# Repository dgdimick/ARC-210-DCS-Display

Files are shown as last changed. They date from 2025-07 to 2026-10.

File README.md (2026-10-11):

# ARC-210 Radio Control Panel for DCS A-10C II using a 3.5" TFT SPI display and DCSBIOS

This project is an ARC-210 radio control panel for the DCS A-10C II using a Teensy 4.1, an ILI9488 TFT display,
and DCS-BIOS for live radio data and cockpit control.

<p align="center">
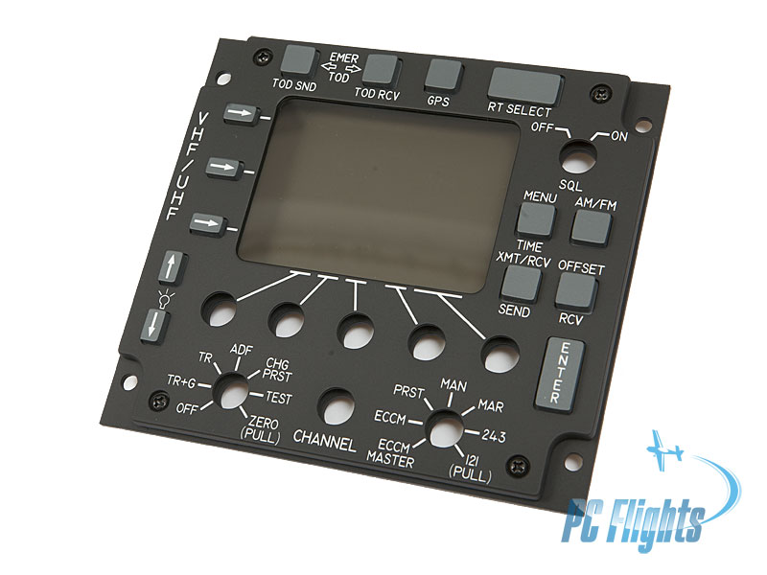
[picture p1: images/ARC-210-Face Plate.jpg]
ARC-210 Face Plate
  
</p>

**October 10, 2026 — Splash-screen picture removed**

I removed `splash_screen.jpg` because [ARC-210-Face Plate.jpg](images/ARC-210-Face%20Plate.jpg) is a better picture. The faceplate picture remains at the top of this README.

**October 10, 2026 — Outdated Button PCB image removed**

I removed `Button_Ver2.0.jpg` because it does not show the final Button PCB. I am redesigning the 16-button board and removed the old picture to prevent confusion.

**October 10, 2026 — Rotary Encoder PCB project published**

I have published the [Rotary Encoder KiCad project](PCBs/Rotary%20Encoders/), including the schematic, PCB, custom libraries and header wiring instructions. The schematic and PCB pass their configured checks. I have confirmed that the printed rotary-encoder STL fits and all six encoders work in the final combined hardware test.

**October 10, 2026 — Final hardware test HEX**

The [final hardware test HEX](Firmware/Test%20Code/ARC210_Final_Hardware_Test_Teensy41.hex) is now available for Teensy 4.1. This combined TFT test checks all 16 buttons, six rotary encoders, brightness controls, and both seven-position rotary switches on GPIO 14 and 15. All of these functions were confirmed working together on the panel. See the [test instructions](Firmware/Test%20Code/ARC210_Button_Test/README.md).

**October 10, 2026 — Two PCBs remaining**

With the combined hardware test confirmed working, the remaining PCB work is the **Main Controller board** and a **redesign of the 16-button board** to improve button alignment with the faceplate.

**Updated October 10, 2026 — Rotary Switch PCB version 1.2 adds On/Off support**

Two new 3D PCB pictures have been uploaded to the `images` directory: the [Rotary Switch PCB](images/Rotary-Switch-PCB-3D.png) and [Rotary Encoder PCB](images/Rotary-Encoder-PCB-3D.png). The new PCBs are still in development. The corrected [Rotary Switch PCB project, version 1.2](PCBs/Rotary%20Switches/), is now available with its schematic, PCB and custom libraries. Terminal 1 is used for the first position, and the PCB matches the corrected schematic. Version 1.2 replaces the withdrawn initial version; use the new files. I modified the PCB so it can also be used with the On/Off switch. For On/Off use, omit R1–R6 and solder across **JP1**, marked **ON/OFF** on the back of the PCB. JP1 connects the R1–R2 junction (R2 pad 1 / switch terminal 2) to GND; connect J1 pin 2 to a Teensy input with a pull-up. For the normal resistor ladder, install R1–R6 and leave JP1 open. The PCB pictures remain available as development previews.

Panel/button illumination LEDs have been dropped due to insufficient clearance with the TFT display. The [parts list](parts/BOM.csv) now excludes the panel LEDs and their current-limiting resistors. The TFT display and its backlight remain. Existing schematic drawings may still show the former panel-lighting circuit.

**September 29, 2026 — Rotary encoder test HEX available**

The current HEX is available for testing the ARC-210 menu screens and navigation, including the HQ, COMSEC, and RADIO SETTINGS menus. This is a menu-system preview, not a finished radio implementation: some menu actions and synchronization still need work.

The current `Master_Program.ino.hex` works with DCS-BIOS while running DCS, but it is **display-only at this time**. It displays radio information from the game; physical panel controls do not yet operate the in-game radio.

The HQ MORE loop and detail screens are implemented. LOAD WOD has been tested against DCS: the displayed number matches, follows MLSK changes, and resets to 20 on re-entry in the tested session. MENU exits from the opening screen listing HQ MENUS / COMSEC / RADIO SETTINGS and is inactive on deeper pages.

Download [Master_Program.ino.hex](Firmware/Master%20Hex%20Files/Master_Program.ino.hex). Read the [preview notes and required DCS-BIOS export changes](Firmware/Master%20Hex%20Files/README.md) before testing. The display starts blank until it receives powered-radio data from DCS-BIOS.

### Rotary encoder test HEX download

Download [ARC210_Encoder_Check_Teensy41.hex](Firmware/Test%20Code/ARC210_Encoder_Check_Teensy41.hex) for standalone testing of all six rotary encoders on a Teensy 4.1. The TFT displays each encoder's raw count, direction, and A/B input states. DCS is not required, and the backlight stays fully on using Teensy pin 4.

**First pass the TFT hello test before loading the encoder test.** A working TFT is required to see the results. See the [test instructions](Firmware/Test%20Code/README.md) and [pin layout](Docs/ARC-210%20Teensy%204.1%20Pin%20layout.txt). Loading this HEX replaces the firmware currently on the Teensy.

Here is a short video showing the progress I have made so far:

[ARC-210 Project Progress Video](https://drive.google.com/file/d/162CAG3RlfPK6QnCSb0p5lkmVlXDZjPrU/view)

I am looking for **beta testers** to help with screen layouts, placement of the lines, and font suggestions. If you have a **3.5-inch SPI TFT display** and a **Teensy 4.1** lying around, you have the basic hardware needed to beta test.

The `Teensy_TFT_Hello_Works.ino` file in the `Firmware` directory contains the correct display pin assignments and can be used to verify that your display is connected correctly.

The HEX file for the current state of the project is located in:

`Firmware/Master Hex Files/`

If you own a Teensy 4.1, you may already know how to install a HEX file. If not, here are the steps.

## Loading the HEX File onto a Teensy 4.1

1. Install and open **Teensy Loader, you can find it in the firmware directory**.
2. Open the supplied `Master_Program.ino.hex` file.
3. Connect the Teensy 4.1 to your computer by USB.
4. Press the button on the Teensy if it does not enter programming mode automatically.
5. Click **Program** in Teensy Loader.
6. Reboot the Teensy.

> **Note:** This repository is now included in the A-10-Sim repository.

This project replicates the look and functionality of the **ARC-210 VHF/UHF radio** used in the A-10C II Warthog module for Digital Combat Simulator (DCS).

It is intended for use with a physical control panel powered by a Teensy 4.1.

[See the official DCS website](https://www.digitalcombatsimulator.com/en/)

## Features

- Interface modeled after the ARC-210 radio
- Powered by one Teensy 4.1
- ILI9488 3.5-inch SPI TFT display (480 × 320)
- Support for digital rotary encoders, rotary switches, and momentary switches
- **Planned button support:** All panel buttons will be wired, and their in-game functions will be supported wherever DCS-BIOS provides the necessary controls. The current HEX remains display-only.
- DCS-BIOS integration for in-game control and feedback
- ARC-210 startup and initialization screens
- Live frequency display from DCS-BIOS
- AM/FM modulation display
- UNAVAILABLE screen for the appropriate Frequency and Mode switch selections

## Tools Needed

- Soldering iron
- 3D printer, or access to one
- Flush wire cutters
- USB Micro-B cable for programming the Teensy 4.1 and connecting the unit to the computer

## Why I had to use a Teensy

The ARC-210 panel needs a lot of GPIO (general-purpose input/output) pins. It is not just driving a display: the same controller also has to read the knobs and switches, scan the buttons, and control the TFT backlight.

- Each rotary encoder needs two input pins to detect movement and direction.
- The 16 push buttons use a 4 × 4 matrix, which still needs eight GPIO pins for its rows and columns.
- The rotary-switch resistor ladders need analog inputs, and the squelch switch needs another input.
- The SPI TFT needs clock and data connections plus control signals for chip select, reset, and data/command selection.
- The TFT display backlight needs a control output.

These connections add up quickly. I chose the Teensy 4.1 because it gives this design enough pins to connect the controls and display directly, without adding GPIO expanders or another controller. Using one controller for all six PCBs also keeps the wiring and firmware easier to manage.

### Could I have used several Arduinos?

Yes. I could have split the buttons and switches onto one Arduino, the rotary encoders onto another, and the TFT onto a controller with enough processing speed and memory for the display. Depending on the DCS-BIOS connection setup, the boards could use separate USB connections or communicate through a main controller.

That would provide more GPIO, but it would also mean more wiring, connections, and separate firmware to maintain. Splitting the controls across boards would not increase the memory or processing speed of the board driving the TFT. An Uno or Mega would still have its own display limitations.

I chose the Teensy 4.1 because it combines the GPIO, processing speed, and memory needed for this design on one board. Several Arduinos were an option; one Teensy keeps this build simpler.

The standard processor clock speeds are:

| Board | CPU clock speed |
| --- | ---: |
| [Teensy 4.1](https://www.pjrc.com/store/teensy41.html) | **600 MHz** |
| [Arduino Uno R3](https://docs.arduino.cc/hardware/uno-rev3/) | **16 MHz** |
| [Arduino Mega 2560 Rev3](https://docs.arduino.cc/hardware/mega-2560/) | **16 MHz** |

The Teensy 4.1 has **37.5 times the CPU clock frequency** of these classic Arduino boards. That is a clock-speed comparison, not a measured 37.5-times improvement in screen refresh rate; processor architecture, memory, SPI speed, and the display code also affect the result.

Display response speed was another major factor in my choice. Compared with classic Arduino Uno and Mega boards, the Teensy 4.1 provides much more processing headroom for drawing the TFT while handling radio updates and controls. I would not expect those older boards to deliver the same screen response with this display and firmware. Actual refresh speed also depends on the SPI connection, display library, and drawing code; this comparison is not a claim about every Arduino model.

### The same Arduino programming workflow

The Teensy is programmed using the same **Arduino IDE** and **`.ino` sketches** used for Arduino boards. The familiar editor, C++ sketch structure, and `setup()` / `loop()` workflow remain the same, so there is no need to learn a different programming environment for this project.

Install [Teensy board support](https://www.pjrc.com/teensy/td_download.html) and select Teensy 4.1 in the IDE. [Teensy Loader](https://www.pjrc.com/teensy/loader.html) handles uploading the compiled firmware and is integrated with the Arduino upload workflow. To use the precompiled `Master_Program.ino.hex` supplied here, simply open it in Teensy Loader and program the board; you do not need to compile the sketch yourself.

The programming workflow is familiar, although pin assignments and hardware-specific libraries still need to match the Teensy rather than an Uno or Mega.

### Cost: one Teensy versus three Arduinos

For a board-only comparison, these US-dollar prices were checked on September 24, 2026:

| Option | Price per board | Quantity | Total |
| --- | ---: | ---: | ---: |
| [Teensy 4.1 without Ethernet — SparkFun](https://www.sparkfun.com/teensy-4-1-without-ethernet.html) | $29.60 | 1 | **$29.60** |
| [Official Arduino Uno R3 — Arduino US store](https://store-usa.arduino.cc/products/arduino-uno-rev3) | $27.60 | 3 | **$82.80** |

At those listed prices, one Teensy costs **$53.20 less** than three official Uno R3 boards, before tax, shipping, cables, headers, or other accessories. Lower-cost Arduino-compatible boards can change the comparison substantially. This is an illustrative cost comparison, not a claim that three Unos would run the current display firmware or provide equivalent screen performance. Prices may change.

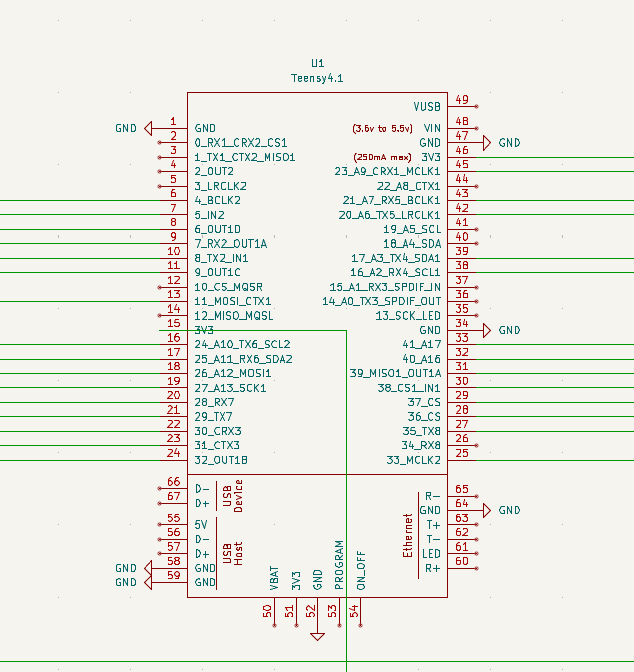
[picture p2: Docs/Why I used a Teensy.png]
Teensy 4.1 schematic showing the panel connections


The numbers around this schematic symbol are KiCad pad numbers; use the signal labels and the project wiring documentation to identify the corresponding Teensy GPIO pins.

## Six-PCB layout

The radio will use a total of **six PCBs**, controlled by one Teensy 4.1:

- **Master PCB:** carries the Teensy, power circuitry, display and control connections.
- **Button PCB:** carries the push-button switches behind the faceplate and connects to the master PCB.
- **Rotary Encoder PCB:** carries the rotary encoders and connects to the master PCB.
- **Three small Rotary Switch PCBs:** the two seven-position switches and the On/Off switch will each have their own PCB for cleaner wiring and better wire support.

All three Rotary Switch PCBs use the same design and are interchangeable. For the **On/Off rotary switch PCB**, install **no resistors** (omit R1–R6) and bridge the small **JP1 solder pad**, marked **ON/OFF**, with solder. For either seven-position rotary switch PCB, install the six resistors and leave JP1 open.

The button, rotary encoder, and rotary switch PCBs do not require additional microcontrollers. The two remaining PCB tasks are the Main Controller board and the redesign of the 16-button board.

## Parts

See the [parts directory](parts/) for the [component list (BOM)](parts/BOM.csv), hardware supplier links, and switch-fit and compatibility notes.

## Software

- Written in Arduino C++
- Uses DCS-BIOS for communication with DCS
- Firmware and test files are maintained in this repository

## ARC-210 Bench Testing App

The [working ARC-210 version of dcsBiosDebug](https://github.com/dgdimick/dcsBiosDebug/tree/arc210-working) is maintained in a separate repository. It provides buttons for menu testing and separate Frequency, Secondary, and Master controls for sending simulated DCS-BIOS data to your Teensy without running DCS.

Download the **arc210-working** branch using **Code → Download ZIP**, extract it, and keep its `icons` folder beside the Python script. With Python 3 and Tkinter installed, open a terminal in that folder and run:

```cmd
python -m pip install numpy pyserial Pillow
python dcsBiosDebug.py
```

Use the Python script, including the `.py` extension; the original bundled executable does not include the ARC-210 controls. Select your Teensy's serial port and click **Connect**. Choose **2 - TR** and click **Set Master** for the normal radio switch position, or **0 - OFF** to test power off.

See the [full testing instructions and compatibility notes](https://github.com/dgdimick/dcsBiosDebug/blob/arc210-working/ARC210_TESTING.md). The shortcuts use fixed A-10C II addresses and send data to the hardware, not commands to DCS. Some firmware states require additional exports through the normal instrument controls.

## Directories

- `ARC-210/` — project root
- `ARC-210/Firmware/` — firmware and test files\n- `ARC-210/Firmware/Boot Loader/` — precompiled Teensy HEX files for loading with Teensy Loader or TyTools
- [`parts/`](parts/) — component list, hardware supplier links, and compatibility notes
- `ARC-210/Docs/` — schematics, diagrams, and documentation
- `ARC-210/images/` — project images
- `ARC-210/Supporting STL's/` — 3D-printable knobs, bezels, brackets, mounts, and other parts

## Supporting STL Files

The `Supporting STL's` directory includes:

- Knobs for rotary encoders and rotary switches
- Mounting hardware for the TFT screen and PCBs
- Brackets for panel alignment

All STL files are intended to be print-ready for FDM printers using a 0.4 mm nozzle. Resin/SLA printers may require different settings or scaling.

## PC Flights affiliation

I am not affiliated with [PC Flights](https://pcflights.com/) in any way. I simply chose to use their panels for my own cockpit projects.

## Licensing

- **PCBs:** CERN Open Hardware Licence Version 2 - Permissive (CERN-OHL-P-2.0)
- **Teensy firmware:** MIT License
- **STL files:** Creative Commons Attribution 4.0 International (CC BY 4.0)

See the `Docs` directory for copies of the applicable licenses.

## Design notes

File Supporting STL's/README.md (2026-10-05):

# ARC-210 Supporting 3D Files

## Knob Set V3

Updated October 4, 2026.

**Knob Set V3** identifies this collection. Each knob retains its own revision number; the collection number does not reset or replace those numbers.

### Current published knobs

| Knob | Current STL | Earlier file |
| --- | --- | --- |
| Frequency | [Freq_Knob_v10.stl](Freq_Knob_v10.stl) | Replaces `Freq Mesh v9.stl` |
| Mode | [Mode_Knob_v4.stl](Mode_Knob_v4.stl) | Supersedes `Mode Mesh v6.stl`, despite its higher filename number |
| Channel | [Channel_Knob_v3.stl](Channel_Knob_v3.stl) | Replaces `Channel Knob v13.stl`, despite its higher filename number |

### If you downloaded an older ZIP

Download the current files linked above. Do not mix the older frequency, mode, or channel STLs with Knob Set V3. The old filenames have been removed from the current branch, but may still exist in previously downloaded ZIPs or repository history.

`Channel_Knob_v3.stl` is the current channel knob for Knob Set V3. Its lower filename number does not mean it is older than `Channel Knob v13.stl`. Use the linked files above to identify the current versions.

### Printing and fit

Use the hardware listed on the main project page. Earlier printing notes reported needing 106% scale for the mode and frequency knobs on the author's printer. That is a historical fit adjustment, not a verified requirement for every current STL or printer. Check shaft fit before printing the full set; scaling changes both the outside dimensions and the holes.

## Display bracket

The 3.5 SPI display mount does not have mounting points. It is a bracket that holds the display between the PCB and front face and currently needs to be hot-glued in place. A proper mounting arrangement is planned.

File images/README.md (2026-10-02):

# Project images and media

[Additional project media (Google Drive)](https://drive.google.com/file/d/1D4GuG0yuVBumasEVbqX7CI54fbOVu1nT/view?usp=sharing)

## Buttons and encoder test

[View the buttons and encoder test, including the menus working with the buttons](https://drive.google.com/file/d/162CAG3RlfPK6QnCSb0p5lkmVlXDZjPrU/view).

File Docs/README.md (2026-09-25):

# ARC-210 Documentation

## Why I used a Teensy

[Why I used a Teensy.png](Why%20I%20used%20a%20Teensy.png) is a screenshot of the Teensy 4.1 symbol and its connections in the ARC-210 panel's KiCad schematic. The green lines are electrical connections to the rest of the circuit. It shows how many connections are needed to bring the display, controls, and lighting together on one controller.

Teensy 4.1 connections in the ARC-210 schematic

### Why the GPIO count matters

GPIO means general-purpose input/output. These are the pins the controller uses to read controls and send signals to other hardware. This panel needs pins for several jobs:

- Rotary encoders each use two input signals to detect movement and direction.
- The 16 buttons use a 4 × 4 matrix, requiring eight pins for the rows and columns instead of a separate pin for every button.
- The SPI TFT needs clock and data signals, plus chip-select, data/command, and reset connections.
- The display backlight and panel lighting have separate control signals.
- Other switches need inputs, and the current pin layout reserves two pins for I²C.

Even with a button matrix, the connections add up quickly. The Teensy 4.1 provides enough pins for this design without adding GPIO expanders or a second controller. That keeps the wiring and firmware easier to manage.

### Could I have used several Arduinos?

Yes. I could have split the buttons and switches onto one Arduino, the rotary encoders onto another, and the TFT onto a controller with enough processing speed and memory for the display. Depending on the DCS-BIOS connection setup, the boards could use separate USB connections or communicate through a main controller.

That would provide more GPIO, but it would also mean more wiring, connections, and separate firmware to maintain. Splitting the controls across boards would not increase the memory or processing speed of the board driving the TFT. An Uno or Mega would still have its own display limitations.

I chose the Teensy 4.1 because it combines the GPIO, processing speed, and memory needed for this design on one board. Several Arduinos were an option; one Teensy keeps this build simpler.

The standard processor clock speeds are:

| Board | CPU clock speed |
| --- | ---: |
| [Teensy 4.1](https://www.pjrc.com/store/teensy41.html) | **600 MHz** |
| [Arduino Uno R3](https://docs.arduino.cc/hardware/uno-rev3/) | **16 MHz** |
| [Arduino Mega 2560 Rev3](https://docs.arduino.cc/hardware/mega-2560/) | **16 MHz** |

The Teensy 4.1 has **37.5 times the CPU clock frequency** of these classic Arduino boards. That is a clock-speed comparison, not a measured 37.5-times improvement in screen refresh rate; processor architecture, memory, SPI speed, and the display code also affect the result.

Display response speed was another major factor in my choice. Compared with classic Arduino Uno and Mega boards, the Teensy 4.1 provides much more processing headroom for drawing the TFT while handling radio updates and controls. I would not expect those older boards to deliver the same screen response with this display and firmware. Actual refresh speed also depends on the SPI connection, display library, and drawing code; this comparison is not a claim about every Arduino model.

### The same Arduino programming workflow

The Teensy is programmed using the same **Arduino IDE** and **`.ino` sketches** used for Arduino boards. The familiar editor, C++ sketch structure, and `setup()` / `loop()` workflow remain the same, so there is no need to learn a different programming environment for this project.

Install [Teensy board support](https://www.pjrc.com/teensy/td_download.html) and select Teensy 4.1 in the IDE. [Teensy Loader](https://www.pjrc.com/teensy/loader.html) handles uploading the compiled firmware and is integrated with the Arduino upload workflow. To use the precompiled `Master_Program.ino.hex` supplied here, simply open it in Teensy Loader and program the board; you do not need to compile the sketch yourself.

The programming workflow is familiar, although pin assignments and hardware-specific libraries still need to match the Teensy rather than an Uno or Mega.

### Cost: one Teensy versus three Arduinos

For a board-only comparison, these US-dollar prices were checked on September 24, 2026:

| Option | Price per board | Quantity | Total |
| --- | ---: | ---: | ---: |
| [Teensy 4.1 without Ethernet — SparkFun](https://www.sparkfun.com/teensy-4-1-without-ethernet.html) | $29.60 | 1 | **$29.60** |
| [Official Arduino Uno R3 — Arduino US store](https://store-usa.arduino.cc/products/arduino-uno-rev3) | $27.60 | 3 | **$82.80** |

At those listed prices, one Teensy costs **$53.20 less** than three official Uno R3 boards, before tax, shipping, cables, headers, or other accessories. Lower-cost Arduino-compatible boards can change the comparison substantially. This is an illustrative cost comparison, not a claim that three Unos would run the current display firmware or provide equivalent screen performance. Prices may change.

### Reading the diagram

The red numbers beside the symbol are KiCad pad numbers, **not necessarily the Teensy GPIO numbers used in the code**. The signal names identify the corresponding functions. Power and ground connections are also shown; they are not extra GPIO pins.

This image is a schematic excerpt, not a complete wiring guide. Use the [ARC-210 Teensy 4.1 pin layout](ARC-210%20Teensy%204.1%20Pin%20layout.txt) for the documented actual GPIO assignments, and check them against the firmware and PCB revision you are building.

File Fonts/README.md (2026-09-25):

# Current ARC-210 display font

The current menu-preview firmware uses `SwanseaFontSimple.cpp` and `SwanseaFontSimple.h`, copied from the working ARC210_Display library. These replace the older FreeSans headers previously stored here.

The renderer uses the Swansea28 bitmap glyph table with fractional scaling:

| Display element | Scale |
| --- | --- |
| Menu labels, EXIT, MORE, RT1 and PREV | 1.25× |
| Large frequency and channel/segment numbers | 3× |
| CT / CT-TD key number | 2× |
| Extra-long menu labels | 1× when needed to fit |

These are rendering scales, not point sizes. The files depend on Arduino and ILI9488_t3 and use the display library's global `tft` object; they are not standalone desktop font files or Adafruit GFX font headers.

Users installing the precompiled HEX do not need to install the fonts separately: the font data is already included in the firmware.

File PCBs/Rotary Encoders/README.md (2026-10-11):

# ARC-210 Rotary Encoder PCB

Published October 10, 2026. KiCad 10 project.

I have checked this six-encoder PCB against its schematic. The electrical check reported zero errors and warnings; the PCB check reported zero violations, zero unconnected pads and zero schematic parity issues under the project's saved check settings. Courtyard and certain footprint checks are disabled in those settings.

I printed the rotary-encoder STL and confirmed that it fits. I have also confirmed all six encoders working in the combined hardware test. A manufactured PCB still needs assembly and testing.

## Open the project

Download this folder and keep its contents together. Open `Rotary Encoders.kicad_pro` in KiCad 10. The custom symbol and footprint libraries are included and use project-relative paths. Install KiCad's standard symbol and footprint libraries as well.

Supplier encoder 3D models are optional and are not bundled. Existing model references now use project-relative paths: place the corresponding `.stp` files beside the project if you have them. The PEC11R model is a visual substitute; use the PEC11H part dimensions for mechanical checks. Missing models do not prevent opening or manufacturing the board.

## Parts and connections

- Six Bourns PEC11H-4220F-S0024 rotary encoders.
- J1: 14-pin header; use the assigned footprint to choose the connector.
- Both J1 pins 13 and 14 connect to GND, as do encoder common contacts and metal mounting tabs.
- The encoders' push-switch contacts S1 and S2 are deliberately unused and marked no-connect.

| J1 pin | Connection |
| --- | --- |
| 1 | SW1 B |
| 2 | SW1 A |
| 3 | SW2 A |
| 4 | SW2 B |
| 5 | SW3 B |
| 6 | SW3 A |
| 7 | SW4 A |
| 8 | SW4 B |
| 9 | SW5 B |
| 10 | SW5 A |
| 11 | SW6 B |
| 12 | SW6 A |
| 13 | GND (encoder commons and mounting tabs) |
| 14 | GND (encoder commons and mounting tabs) |

The tested physical Teensy GPIO pairs are: SW1 = 16/17, SW2 = 28/29, SW3 = 20/21, SW4 = 22/23, SW5 = 24/25 and SW6 = 26/27. Ensure all encoder commons share Teensy GND. The final [combined hardware test HEX](../../Firmware/Test%20Code/ARC210_Final_Hardware_Test_Teensy41.hex) provides counts and A/B diagnostics.

## Manufacturing files

This upload contains the editable project. Export copper, silkscreen, solder-mask and Edge.Cuts Gerbers plus drill files from KiCad for your PCB manufacturer. Review the manufacturer's preview before ordering.

PCB licensing: CERN-OHL-P-2.0, as specified in the repository.

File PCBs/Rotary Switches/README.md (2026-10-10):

# ARC-210 Rotary Switch PCB — Version 1.2

Updated October 10, 2026.

This corrected KiCad 10 project replaces the withdrawn initial version. Switch terminal 1 is used for position 1. The resistor ladder uses **six resistors (R1–R6)** to provide seven switch-position voltages. The switch contacts used are 1, 2, 4, 5, 7, 8 and 10; terminal 11 is unused. A1 is the common contact and analog output.

Open `Rotary Switches.kicad_pro`. The project includes its custom symbol and A12505RNCQ footprint, with relative library paths so they work after downloading.

- SW1: C&K A12505RNCQ, PCB terminals, 12.7 mm shaft, 45° indexing.
- R1–R6: **six resistors**, each 1 kΩ, 1%, 1/8 W.
- J1: pin 1 = 3.3 V; pin 2 = analog output; pin 3 = GND.

The 220 Ω resistor and 100 nF input filter belong near the Teensy on the master PCB.

## On/Off option added in version 1.2

I modified the PCB so it can also be used with the On/Off switch. **JP1**, marked **ON/OFF** on the back of the PCB near R2, is an open solder jumper between GND and the R1–R2 junction: R2 pad 1, also connected to switch terminal 2.

- **On/Off:** omit all six resistors R1–R6 and bridge JP1 with solder. Connect J1 pin 2 (switch common A1) to a Teensy input configured with a pull-up, and J1 pin 3 to GND. Selecting terminal 2 pulls the input LOW; an ungrounded contact reads HIGH. J1 pin 1 is not needed for this configuration. Set the switch travel and contact selection to match the panel markings.
- **Resistor ladder:** fit all six resistors R1–R6 and leave JP1 open. Use the three J1 connections listed above.

The solder-lug A12515RNZQ still requires mechanical support and wires to the corresponding PCB connections; it does not fit the PCB-pin footprint directly.

Validation: KiCad electrical checks reported zero violations; PCB checks reported zero violations, zero unconnected pads and zero schematic parity issues under the project's configured checks. Physical fit and operation have not yet been verified on a manufactured board.

The optional supplier 3D model is not bundled. To display it, place `A12503RNCQE.stp` beside the project files. That model represents the shorter shaft and is a visual reference; use the actual A12505RNCQ dimensions for mechanical clearance.

PCB design licensing: CERN-OHL-P-2.0, as specified in the repository.

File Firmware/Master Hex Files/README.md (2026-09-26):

# ARC-210 menu-system preview

README last updated: **September 25, 2026**.

`Master_Program.ino.hex` is the current Teensy 4.1 / ILI9488 480 × 320 display firmware, published for menu-screen and navigation testing. It is not a complete implementation of every radio function.

## What to test

- HQ MORE sequence: OPER. DATE LOAD -> VERIFY WOD/MWOD -> WOD LOAD -> WOD ERASE -> HQ II FMT -> OPER. DATE LOAD -> VERIFY WOD/MWOD, repeating from there.
- HQ detail screens, including WOD and HQII number positioning.
- MENU opens the opening menu from the frequency screen and closes it from that opening menu only. On all deeper pages it is inactive.
- LOAD WOD number synchronization with DCS, including MLSK increments. In the tested session both displays reset to 20 on re-entry; this is supplied by DCS, not hard-coded.
- LOAD HQII FMT exits to frequency when a frequency knob or Channel knob moves.
- Existing COMSEC and RADIO SETTINGS screen navigation.

## Known limitations

Some detail-page actions remain unimplemented, including the WOD erase YES outcome. COMSEC BASEBAND/DIPHASE selection synchronization needs further work because the game label depends on underlying settings. Early aircraft-power startup screens may lag DCS; frequency-screen timing and power behavior have been tested. Report the exact page, button/knob, and both DCS and physical-screen behavior when reporting an issue.

## Loading and first startup

Open this HEX in Teensy Loader, enable Auto, and press the Teensy's programming button. Reconnect your DCS-BIOS serial bridge after flashing if needed. The display starts blank until it receives powered-radio data; a blank screen without powered-radio updates from DCS-BIOS or dcsBiosDebug is expected. The Loader's “1% used” is memory usage, not upload progress.

## Test the menu system without running DCS

Use [dcsBiosDebug](https://github.com/dgdimick/dcsBiosDebug) to send simulated DCS-BIOS updates to the Teensy over USB serial. This lets you exercise the firmware's menu screens and navigation without launching DCS or loading a mission. See its [README and download links](https://github.com/dgdimick/dcsBiosDebug#downloads) for installation.

1. Load `Master_Program.ino.hex` onto the Teensy and connect the display hardware.
2. Close the DCS-BIOS serial bridge and any Serial Monitor using the Teensy's COM port.
3. In dcsBiosDebug, click **Find Serial Ports**, select the Teensy's COM port, and click **Connect**.
4. Load the matching A-10C aircraft JSON definition from your DCS-BIOS `doc/json` directory. Its output addresses and masks must match this firmware.
5. Add the ARC-210 power/master-switch and display-state outputs to **Active Indicators**. Send powered-radio values, including valid frequency/display data, and allow startup to finish. Connecting alone does not turn on the simulated radio; the screen can remain blank until the required data arrives.
6. Add the ARC-210 MENU, upper/middle/lower line-select key, and XMT/RCV button outputs. Simulate each press as **0 -> 1 -> 0**, allowing each state to be transmitted before changing it again. The firmware acts on the transition to 1, so release the button before testing another press.
7. Use these simulated updates to check the menu sequence, labels, layout, and navigation described above. Text outputs can be edited and sent with the **>** button; integer outputs can be changed with their sliders.

This is a bench test of the firmware's response to supplied data. dcsBiosDebug does not simulate DCS's radio logic or automatically provide the game's responses to hardware commands. Features such as WOD synchronization and game-dependent settings still need an in-DCS test. Disconnect dcsBiosDebug before reconnecting the normal DCS-BIOS serial bridge.

## DCS-BIOS export requirements

This build was tested with local changes to the A-10C DCS-BIOS export. Stock exports do not provide all the values used by these HQ screens. Back up your installed `Saved Games/DCS/Scripts/DCS-BIOS/lib/modules/aircraft_modules/A-10C.lua` before adapting the two existing getters below. Keep their existing lengths, ordering, and addresses; do not add duplicate definitions.

For `ARC210_VERIFY_WOD_ACTIVE_CHANNEL` (two characters, address `0x1338`), use:

```lua
return Functions.coerce_nil_to_string(arc_210_data["WOD_segment"] or arc_210_data["HQII_segment"] or arc_210_data["active_oper_date"] or arc_210_data["active_channel"])
```

For `ARC210_SELECTED_RT` (three characters, address `0x1320`), use:

```lua
return Functions.coerce_nil_to_string(arc_210_data["txt_RT"] or (arc_210_data["POWER UP LOADER"] and "PWR"))
```

Fully close and restart DCS after these changes. Reloading a mission or flashing the Teensy does not reload the Lua export. DCS-BIOS updates may overwrite these customizations. These getters only read the game's display data.

## File verification

Firmware build: **September 23, 2026**, originally published September 24, 2026. The September 25 README update adds offline testing instructions; the HEX file has not changed or been recompiled.

SHA-256:

```text
607418aa3843d871f3b5ff98abc2ede7575086a80b34e2273da59c333469278c
```

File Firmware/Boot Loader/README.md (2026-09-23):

# ARC-210 Teensy Firmware and Boot Loader Files

This directory contains the precompiled Teensy 4.1 firmware files for the ARC-210 DCS Display project. These files can be installed without compiling the Arduino source code.

The firmware files use the `.hex` extension.

## TyTools

You can find the complete TyTools instructions on the [official TyTools website](https://koromix.dev/tytools).

TyTools is a collection of independent programs for uploading firmware to, monitoring, and managing Teensy boards. Only one executable is needed for the function you want to use.

| Tool | Type | Description |
| --- | --- | --- |
| **TyCommander** | Qt graphical application | Upload, monitor, and communicate with multiple Teensy boards |
| **TyUploader** | Qt graphical application | Simple firmware and sketch uploader |
| **tycmd** | Command line | Command-line tool for managing Teensy boards |

Download the [latest TyTools release from GitHub](https://github.com/Koromix/tytools/releases). Development builds are available from [koromix.dev](https://koromix.dev/files/tytools/).

## Uploading with TyCommander or TyUploader

1. Download and install TyTools.
2. Connect the Teensy 4.1 to the computer with a USB cable.
3. Open **TyCommander** or **TyUploader**.
4. Select the Teensy 4.1.
5. Select the appropriate ARC-210 `.hex` file from this directory.
6. Start the upload.
7. If requested, press the physical programming button on the Teensy.

## Using `tycmd`

### List connected Teensy boards

```text
tycmd list
```

Use `--verbose` for additional device information:

```text
tycmd list --verbose
```

For structured output that can be processed by a script:

```text
tycmd list --output json
```

### Upload firmware

From this directory, upload a HEX file with:

```text
tycmd upload "<firmware-file>.hex"
```

If you run the command from the repository root, use:

```text
tycmd upload "Firmware/Boot Loader/<firmware-file>.hex"
```

Replace `<firmware-file>.hex` with the actual firmware filename.

By default, `tycmd` attempts to reboot the Teensy into its bootloader. Use `--wait` if you want it to wait for the bootloader to appear or for you to press the Teensy's programming button:

```text
tycmd upload --wait "Firmware/Boot Loader/<firmware-file>.hex"
```

## Selecting a Specific Teensy

When multiple Teensy boards are connected, select one with:

```text
tycmd <command> --board "[<serial>][-<family>][@<location>]"
```

The serial number, board family, and USB or operating-system location are optional filters. Run `tycmd list` to see the identifiers available on your computer.

| Board filter | Effect |
| --- | --- |
| `714230` | Select the board with serial number 714230 |
| `-Teensy` | Select a board in the Teensy family |
| `@usb-1-2-2` | Select the board connected at USB location `usb-1-2-2` |
| `@COM1` | Select the board associated with COM1 |
| `714230@usb-1-2-2` | Match both the serial number and USB location |

Examples:

```text
tycmd upload --board "714230" "Firmware/Boot Loader/<firmware-file>.hex"
tycmd upload --board "@COM5" "Firmware/Boot Loader/<firmware-file>.hex"
tycmd upload --board "@usb-1-2-2" "Firmware/Boot Loader/<firmware-file>.hex"
```

Using the USB-location form is useful in a simulator containing several Teensy boards because a device can remain associated with the same physical USB port.

## Serial Monitor

Open a serial connection with:

```text
tycmd monitor
```

Use `--reconnect` to reconnect automatically after a reset or brief USB disconnection:

```text
tycmd monitor --reconnect
```

Use `--raw` to send terminal input immediately without line buffering:

```text
tycmd monitor --raw
```

Teensy is a native USB device, so normal serial baud-rate settings are generally ignored by TyTools.

## Reset and Bootloader Commands

Restart the Teensy:

```text
tycmd reset
```

Start the Teensy bootloader, equivalent to pressing its physical programming button:

```text
tycmd reset -b
```

Display general or command-specific help:

```text
tycmd help
tycmd help upload
tycmd help monitor
```

## Additional Information

TyTools identifies boards by their USB topology, allowing multiple Teensy devices to be managed independently. A board that remains connected to the same USB port can continue to be recognized at the same USB location even when it changes between normal operation and bootloader mode.

TyTools is released into the public domain. Refer to the [TyTools repository](https://github.com/Koromix/tytools) and its license information for details.

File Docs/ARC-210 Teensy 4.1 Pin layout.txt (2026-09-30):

Pin Layout

ARC-210 Teensy 4.1

| Function | Actual Teensy GPIO |
| --- | ---: |
| Panel LED PWM  | 5 |
| TFT BLK PWM | 4 |
| TFT RESET | 8 |
| TFT MOSI | 11 |
| TFT DC/RS | 9 |
| TFT CS | 10 |
| TFT SCK | 13 |
| Encoder 1 | 16, 17 |
| Encoder 2 | 28, 29 |
| Encoder 3 | 20, 21 |
| Encoder 4 | 22, 23 |
| Encoder 5 | 24, 25 |
| Encoder 6 | 26, 27 |
| Matrix rows | 30, 31, 32, 33 |
| Matrix columns | 35, 36, 37, 40 |
| SPST | 41 |
| I²C reserved | 18, 19 |

TFT BLK PWM wiring (confirmed working):
- Teensy board printed pin label: 4
- GPIO / Arduino code pin number: 4
- KiCad Teensy symbol U1 terminal number: 6
These identify the same connection. BLK uses GPIO 4, not GPIO 6.
Reserve this connection for the display backlight PWM.
PWM dimming has been verified in the standalone test. Integration into
Master_Program is deferred until the final test.

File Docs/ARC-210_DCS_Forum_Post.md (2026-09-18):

I’m starting a **DCS-BIOS ARC-210 project**.

So far, I’ve completed the schematic and have the Teensy communicating with DCS-BIOS and successfully displaying the current ARC-210 frequency on the TFT.

My plan is to release everything needed for someone to build their own unit, including:

- PCB manufacturing files
- Schematics
- Knob STL files
- Any other required 3D-printable parts
- Firmware
- Test code and documentation

I also plan to release the firmware as a **HEX file**, so someone who isn’t a programmer should still be able to flash the Teensy without having to compile the source code.

Because this project will handle all **16 buttons**, the rotary encoders, rotary switches, TFT display, and the other ARC-210 controls, I’m using a **Teensy 4.1** as the controller.

If you build one yourself, I expect the total cost to be **under $200 USD**, depending on where you source the parts.

I’ve also set up a GitHub repository where I’ll post project updates and files as the build progresses. There is already some test firmware available, including a basic TFT test that displays “Hello World” so you can verify that the Teensy and SPI TFT display are wired and working correctly.

I’ve been working on this project on and off for roughly the last **18 months**. I’ve had to stop a few times because of the cost of parts and PCB development, but I’m now getting back into it and making good progress.

All of the code I’m writing for the project is my own. The project will be released under several licenses depending on the type of file:

- **PCB, schematics, and hardware design:** CERN Open Hardware Licence Version 2 – Permissive (CERN-OHL-P-2.0)
- **Teensy firmware/software:** MIT License
- **STL files and other 3D/visual assets:** Creative Commons Attribution 4.0 International (CC BY 4.0)

Here’s a short video showing the Teensy connecting to the ARC-210 through DCS-BIOS and receiving the current radio frequency:

https://drive.google.com/file/d/1iOCoj9Os1fUJ6zFHfCuTmOncaygpXLH4/view?usp=drive_link

GitHub repository:

https://github.com/dgdimick/ARC-210-DCS-Display

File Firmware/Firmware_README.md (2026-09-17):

# Firmware

This folder contains the firmware used for the ARC-210 controller project.

## Test Code

The `Test Code` folder contains small test programs intended to help builders verify individual parts of their controller during assembly and troubleshooting.

These test programs can be used to check things such as:

- Teensy 4.1 operation
- TFT display operation
- TFT pin assignments
- USB serial communication
- DCS-BIOS communication
- Switches and rotary encoders
- LEDs and backlighting
- Other controller inputs and outputs

The test code is not necessarily the final ARC-210 firmware. It is provided as a troubleshooting and bring-up aid so that each part of the controller can be tested individually before the complete firmware is loaded.

When building the controller, it is recommended to test each major section as it is completed. This can make it much easier to find wiring, pin-assignment, or hardware problems before the entire controller is assembled.

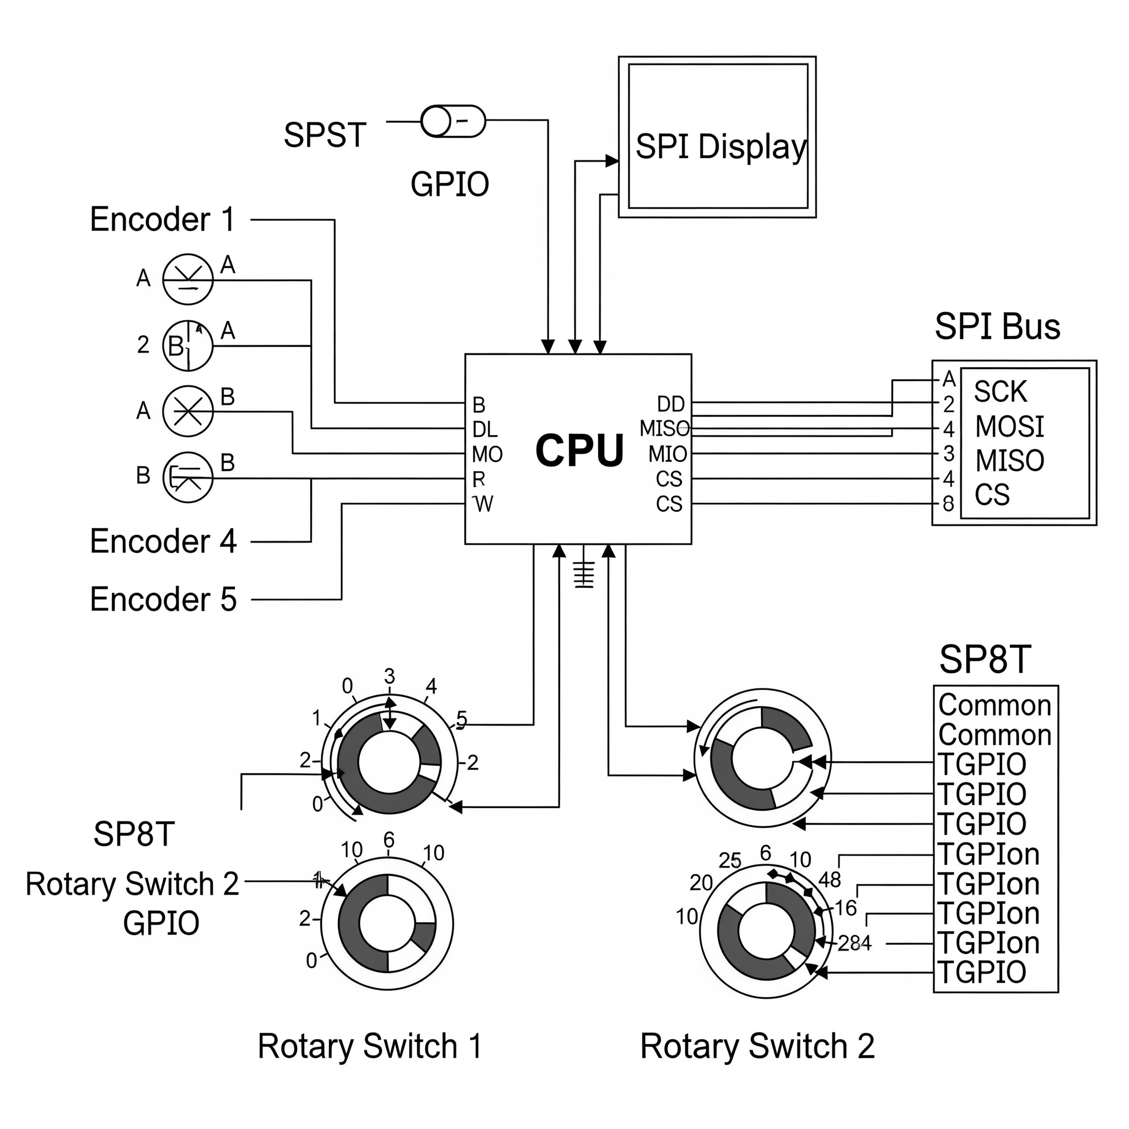
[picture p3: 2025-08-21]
Docs/Example Design.png

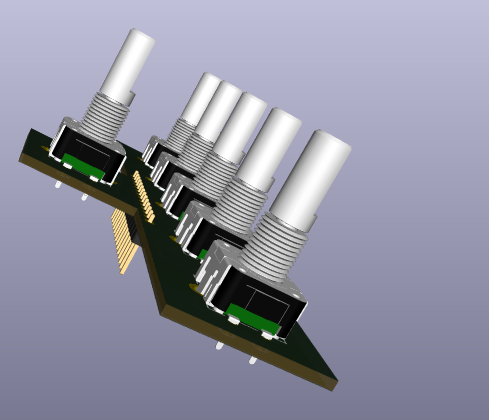
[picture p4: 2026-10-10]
images/Rotary-Encoder-PCB-3D.png

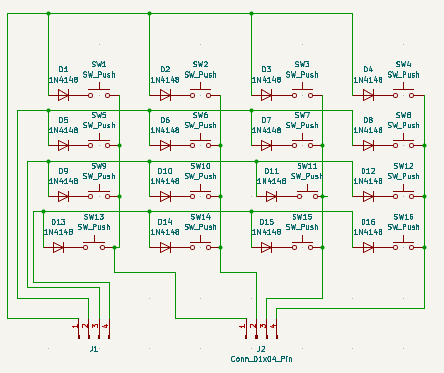
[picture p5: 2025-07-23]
images/control_layout.png

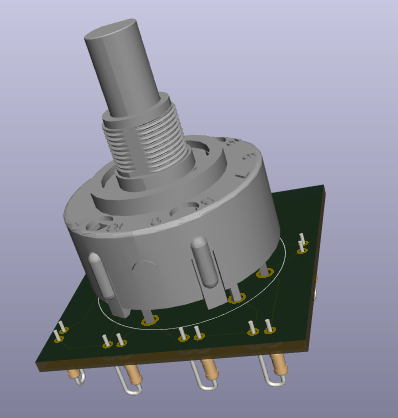
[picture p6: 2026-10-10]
images/Rotary-Switch-PCB-3D.png

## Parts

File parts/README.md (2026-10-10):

# Parts

Updated October 10, 2026.

[View the component list (BOM.csv)](BOM.csv)

The BOM lists schematic references, values, footprints, quantities, and do-not-populate flags for the ARC-210 master board. It is based on a September 25 snapshot of the [KiCad project](https://github.com/dgdimick/Teensy/tree/main/KiCad/ARC-210_Master_Board), with subsequent parts-selection updates, not a finalized purchasing list. Blank footprints and generic diode values still need confirmation. Panel hardware and supplier links are listed below because the schematic BOM does not describe every mechanical part.

## Five-PCB layout

The build uses five PCBs controlled by one Teensy 4.1: the master PCB, button PCB, rotary encoder PCB, and two small rotary switch PCBs. The separate control boards provide cleaner wiring and wire support.

## BOM coverage

[BOM.csv](BOM.csv) originated from the ARC-210 master-board schematic and includes subsequent panel-hardware selections. Panel-hardware entries are explicitly labelled so their references are not confused with master-board references. This is not yet a finalized set of board-specific purchasing lists; do not multiply quantities by the number of PCBs.

The corrected [Rotary Switch KiCad project, version 1.2](../PCBs/Rotary%20Switches/), replaces the withdrawn initial version. Version 1.2 retains the corrected pin assignments and adds an ON/OFF solder jumper. Omit R1–R6 and bridge JP1 for On/Off operation; fit the resistors and leave JP1 open for resistor-ladder operation. See the project instructions for wiring and pull-up configuration.

## Panel illumination removed — October 6, 2026

The panel/button illumination LEDs have been dropped because there is insufficient clearance with the TFT display in the current mechanical layout. The PC Flights panel I am using also has no buttons that can be illuminated by the LEDs—all of the buttons are painted. The parts list no longer includes the 16 panel LEDs (D21–D36) or their 16 current-limiting resistors (R21–R36). The TFT display and its backlight remain, as does the separate power indicator LED.

This update changes the documentation and parts list only; existing schematic drawings may still show the former panel-lighting circuit.

## Main Controller power and protection parts

I am including the following power-input and protection components from the current Main Controller schematic. These entries are already included in [BOM.csv](BOM.csv); the quantities below are for one Main Controller board.

| Reference | Part / value | Quantity |
| --- | --- | ---: |
| J3 | DC barrel power-input jack, labelled 5.0–5.5 V input in the current schematic | 1 |
| F2 | Resettable PTC fuse, 1.1 A hold current | 1 |
| D1 | SB560 Schottky diode | 1 |
| C5 | 470 µF, 10 V electrolytic capacitor | 1 |
| C6 | 100 nF (0.1 µF) capacitor | 1 |
| D2 | Green power indicator LED, 5 mm footprint | 1 |
| R15 | 1 kΩ resistor | 1 |
| D3 | 1N4734A, 5.6 V Zener diode | 1 |
| R16 | 220 Ω resistor | 1 |
| R17 | 1 kΩ resistor | 1 |
| Q2 | C106D SCR | 1 |

The TFT backlight control on the Main Controller also uses **Q3: IRLZ44N MOSFET**, **R37: 10 kΩ**, and **R38: 100 Ω**, one of each. These are also listed in the BOM.

I still need to finalize the Main Controller PCB. The exact barrel-jack size, PTC ordering code, resistor wattages and unfinished footprints need to be confirmed against that final design. This section records the current schematic parts; it does not add an external power supply to the purchasing list.

## Current button switches

Use **16 switches per panel**, each **6 × 6 × 6 mm**, SPST momentary tactile, with four through-hole leads. The body still occupies 6 × 6 mm on the board.

The selected generic footprint is `Button_Switch_THT:SW_PUSH-6mm`. Confirm the purchased switches' lead spacing and contact pairing against it before fabrication.

## Hardware selection and supplier links

**Note:** This is intended to be a relatively simple design.

- **Microcontroller:** Teensy 4.1 without Ethernet  
  [SparkFun](https://www.sparkfun.com/teensy-4-1-without-ethernet.html)

- **Display:** ILI9488 SPI TFT, 3.5-inch  
  [Amazon](https://www.amazon.com/dp/B0CKRJ81B5?ref_=ppx_hzsearch_conn_dt_b_fed_asin_title_2)

- **Encoders:** Six Bourns **PEC11H-4220F-S0024**, matching the current encoder PCB. These have PCB terminals and an integrated push switch. The older seven-encoder quantity and 4215 shaft-option links are superseded.  
  [Mouser — 652-PEC11H4220FS0024](https://www.mouser.com/en/ProductDetail/Bourns/PEC11H-4220F-S0024?qs=7MVldsJ5UayW2mw8xYm74g%3D%3D)

- **Multi-position rotary switches:** Two C&K **A12505RNCQ**, with 1/2-inch (12.7 mm) shafts, 45-degree indexing and **C PCB-pin terminals**. These replace the solder-lug versions for the two resistor-ladder PCBs. The circuit uses seven positions of each eight-position switch; verify the corrected wiring and stop-ring setting against the panel.  
  [Mouser — 611-A12505RNCQ](https://www.mouser.com/en/ProductDetail/CK/A12505RNCQ?qs=h7H1bHRqGz9AS0MdXl06Aw%3D%3D) · [C&K datasheet](https://www.ckswitches.com/media/1349/arotary.pdf)

- **SQL On/Off switch:** One C&K **A12515RNZQ**, with a 1-1/2-inch (38.1 mm) shaft, 45-degree indexing and **Z solder-lug terminals**. Mount it in a bracket and wire its contacts to the Teensy input. It does not mount directly in the PCB-pin footprint and does not need a resistor ladder. The panel's ON and OFF markings are two clicks (90 degrees) apart; confirm the contact selection and travel stops against those markings.  
  [Mouser](https://www.mouser.com/ProductDetail/CK/A12515RNZQ) · [C&K datasheet](https://www.ckswitches.com/media/1349/arotary.pdf)

- **Faceplate:** A-10C "Thunderbolt" / "Warthog" VHF/UHF cockpit panel  
  [PC Flights](https://pcflights.com/a-10c-thunderbolt-warthog-vhf-uhf-panel/)

- **Button switches:** 16 per panel, 6 × 6 × 6 mm SPST momentary tactile push-button switches, four-pin through-hole  
  [Amazon](https://www.amazon.com/dp/B0HGBSFY2L)

- **PCB standoffs:** Vibit 640-piece M3 nylon standoff assortment, including male–female and female–female spacers with screws. Select lengths to suit the final PCB spacing; the required lengths and quantity per panel are not yet finalized.  
  [Amazon](https://www.amazon.com/dp/B0H1QS5Q6N)

- **Diodes:** 16 × 1N4148 small-signal fast-switching diodes, DO-35  
  These are optional; jumper wires may be used in their place where appropriate.  
  [Amazon](https://www.amazon.com/100-Pieces-1N4148-Switching-High-Speed/dp/B079KJ91JZ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)

[Back to the project README](../README.md)

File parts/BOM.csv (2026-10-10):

Refs | Value | Footprint | Qty | DNP
C1 | 100nF | Capacitor_THT:C_Disc_D5.0mm_W2.5mm_P2.50mm | 1
C2 | 100nF | Capacitor_THT:C_Disc_D5.0mm_W2.5mm_P2.50mm | 1
C5 | 470uF 10V | Capacitor_THT:CP_Radial_D8.0mm_P3.50mm | 1
C6 | 0.1uF | Capacitor_THT:C_Disc_D5.0mm_W2.5mm_P5.00mm | 1
CHANNEL1 | Encoder 6 | Connector_PinHeader_2.54mm:PinHeader_1x03_P2.54mm_Vertical | 1
D1 | SB560 | Diode_THT:D_DO-201AD_P15.24mm_Horizontal | 1
D2 | POWER GREEN | LED_THT:LED_D5.0mm | 1
D3 | 1N4734A 5.6V | Diode_THT:D_DO-41_SOD81_P10.16mm_Horizontal | 1
D5 | D | Diode_THT:D_DO-35_SOD27_P7.62mm_Horizontal | 1
D6 | D | Diode_THT:D_DO-35_SOD27_P7.62mm_Horizontal | 1
D7 | D | Diode_THT:D_DO-35_SOD27_P7.62mm_Horizontal | 1
D8 | D | Diode_THT:D_DO-41_SOD81_P10.16mm_Horizontal | 1
D9 | D | Diode_THT:D_DO-35_SOD27_P7.62mm_Horizontal | 1
D10 | D | Diode_THT:D_DO-35_SOD27_P7.62mm_Horizontal | 1
D11 | D | Diode_THT:D_DO-35_SOD27_P7.62mm_Horizontal | 1
D12 | D | Diode_THT:D_DO-35_SOD27_P7.62mm_Horizontal | 1
D13 | D | Diode_THT:D_DO-35_SOD27_P7.62mm_Horizontal | 1
D14 | D | Diode_THT:D_DO-35_SOD27_P7.62mm_Horizontal | 1
D15 | D | Diode_THT:D_DO-35_SOD27_P7.62mm_Horizontal | 1
D16 | D | Diode_THT:D_DO-35_SOD27_P7.62mm_Horizontal | 1
D17 | D | Diode_THT:D_DO-35_SOD27_P7.62mm_Horizontal | 1
D18 | D | Diode_THT:D_DO-35_SOD27_P7.62mm_Horizontal | 1
D19 | D | Diode_THT:D_DO-35_SOD27_P7.62mm_Horizontal | 1
D20 | D | Diode_THT:D_DO-35_SOD27_P7.62mm_Horizontal | 1
F2 | 1.1A HOLD PTC |  | 1
FREQ_Mode2 | Conn_01x09_Pin | Connector_PinHeader_2.54mm:PinHeader_1x09_P2.54mm_Vertical | 1
J1 | SPI Display | Connector_PinHeader_2.54mm:PinHeader_1x08_P2.54mm_Vertical | 1
J3 | 5.0V-5.5V INPUT |  | 1
J4 | FREQ1 | Connector_PinHeader_2.54mm:PinHeader_1x03_P2.54mm_Vertical | 1
J5 | FREQ2 | Connector_PinHeader_2.54mm:PinHeader_1x03_P2.54mm_Vertical | 1
J6 | FREQ3 | Connector_PinHeader_2.54mm:PinHeader_1x03_P2.54mm_Vertical | 1
J7 | FREQ4 | Connector_PinHeader_2.54mm:PinHeader_1x03_P2.54mm_Vertical | 1
J8 | FREQ5 | Connector_PinHeader_2.54mm:PinHeader_1x03_P2.54mm_Vertical | 1
OP_Mode1 | Conn_01x09_Pin | Connector_PinHeader_2.54mm:PinHeader_1x09_P2.54mm_Vertical | 1
Q2 | C106D SCR |  | 1
Q3 | IRLZ44N | Package_TO_SOT_THT:TO-220-3_Vertical | 1
R1 | 220 | Resistor_THT:R_Axial_DIN0204_L3.6mm_D1.6mm_P5.08mm_Horizontal | 1
R2 | 220 | Resistor_THT:R_Axial_DIN0204_L3.6mm_D1.6mm_P5.08mm_Horizontal | 1
R3 | 1k 1% | Resistor_THT:R_Axial_DIN0309_L9.0mm_D3.2mm_P12.70mm_Horizontal | 1
R4 | 1k 1% | Resistor_THT:R_Axial_DIN0309_L9.0mm_D3.2mm_P12.70mm_Horizontal | 1
R5 | 1k 1% | Resistor_THT:R_Axial_DIN0207_L6.3mm_D2.5mm_P10.16mm_Horizontal | 1
R6 | 1k 1% | Resistor_THT:R_Axial_DIN0207_L6.3mm_D2.5mm_P10.16mm_Horizontal | 1
R7 | 1k 1% | Resistor_THT:R_Axial_DIN0207_L6.3mm_D2.5mm_P10.16mm_Horizontal | 1
R8 | 1k 1% | Resistor_THT:R_Axial_DIN0207_L6.3mm_D2.5mm_P10.16mm_Horizontal | 1
R9 | 1k 1% | Resistor_THT:R_Axial_DIN0207_L6.3mm_D2.5mm_P10.16mm_Horizontal | 1
R10 | 1k 1% | Resistor_THT:R_Axial_DIN0207_L6.3mm_D2.5mm_P10.16mm_Horizontal | 1
R11 | 1k 1% | Resistor_THT:R_Axial_DIN0207_L6.3mm_D2.5mm_P10.16mm_Horizontal | 1
R12 | 1k 1% | Resistor_THT:R_Axial_DIN0207_L6.3mm_D2.5mm_P10.16mm_Horizontal | 1
R13 | 1k 1% | Resistor_THT:R_Axial_DIN0207_L6.3mm_D2.5mm_P10.16mm_Horizontal | 1
R14 | 1k 1% | Resistor_THT:R_Axial_DIN0207_L6.3mm_D2.5mm_P10.16mm_Horizontal | 1
R15 | 1k |  | 1
R16 | 220 |  | 1
R17 | 1k |  | 1
R37 | 10K | Resistor_THT:R_Axial_DIN0207_L6.3mm_D2.5mm_P10.16mm_Horizontal | 1
R38 | 100 | Resistor_THT:R_Axial_DIN0207_L6.3mm_D2.5mm_P10.16mm_Horizontal | 1
SQL1 | Conn_01x02_Pin | Connector_PinHeader_2.54mm:PinHeader_1x02_P2.54mm_Vertical | 1
SW1 | SW_Push 6x6x6mm SPST momentary | Button_Switch_THT:SW_PUSH-6mm | 1
SW2 | SW_Push 6x6x6mm SPST momentary | Button_Switch_THT:SW_PUSH-6mm | 1
SW3 | SW_Push 6x6x6mm SPST momentary | Button_Switch_THT:SW_PUSH-6mm | 1
SW4 | SW_Push 6x6x6mm SPST momentary | Button_Switch_THT:SW_PUSH-6mm | 1
SW5 | SW_Push 6x6x6mm SPST momentary | Button_Switch_THT:SW_PUSH-6mm | 1
SW6 | SW_Push 6x6x6mm SPST momentary | Button_Switch_THT:SW_PUSH-6mm | 1
SW7 | SW_Push 6x6x6mm SPST momentary | Button_Switch_THT:SW_PUSH-6mm | 1
SW8 | SW_Push 6x6x6mm SPST momentary | Button_Switch_THT:SW_PUSH-6mm | 1
SW9 | SW_Push 6x6x6mm SPST momentary | Button_Switch_THT:SW_PUSH-6mm | 1
SW10 | SW_Push 6x6x6mm SPST momentary | Button_Switch_THT:SW_PUSH-6mm | 1
SW11 | SW_Push 6x6x6mm SPST momentary | Button_Switch_THT:SW_PUSH-6mm | 1
SW12 | SW_Push 6x6x6mm SPST momentary | Button_Switch_THT:SW_PUSH-6mm | 1
SW13 | SW_Push 6x6x6mm SPST momentary | Button_Switch_THT:SW_PUSH-6mm | 1
SW14 | SW_Push 6x6x6mm SPST momentary | Button_Switch_THT:SW_PUSH-6mm | 1
SW15 | SW_Push 6x6x6mm SPST momentary | Button_Switch_THT:SW_PUSH-6mm | 1
SW16 | SW_Push 6x6x6mm SPST momentary | Button_Switch_THT:SW_PUSH-6mm | 1
U1 | Teensy4.1 | Teensy:Teensy41 | 1
SQL panel hardware (not a schematic reference) | C&K A12515RNZQ - SQL On/Off; 38.1mm shaft; 45deg indexing; bracket mount; solder lugs |  | 1
Rotary switch panel hardware (not master-board references) | C&K A12505RNCQ - multi-position rotary switch; 12.7mm shaft; 45deg indexing; PCB pins | ARC210_RotarySwitches:A12505RNCQ | 2
Encoder PCB hardware (not master-board references) | Bourns PEC11H-4220F-S0024 - rotary encoder with push switch; PCB terminals | ARC210_Encoders:PEC11H4220FS0024 | 6

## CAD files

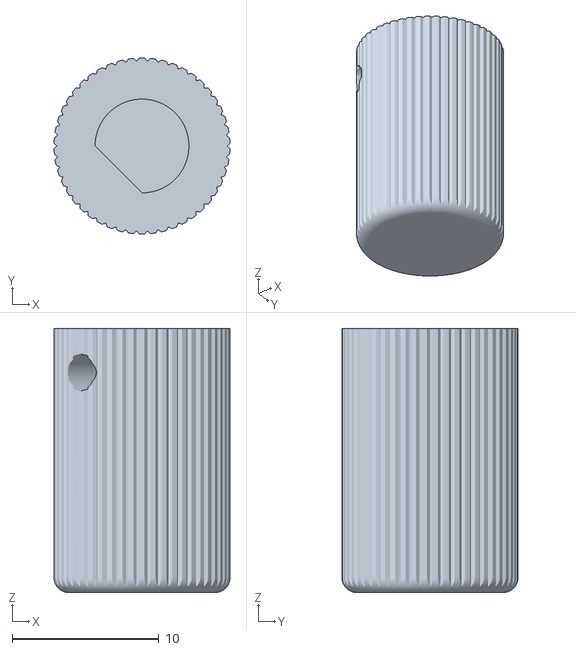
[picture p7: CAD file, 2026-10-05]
Supporting STL's/Channel_Knob_v3.stl
12.0 x 12.0 x 18.0

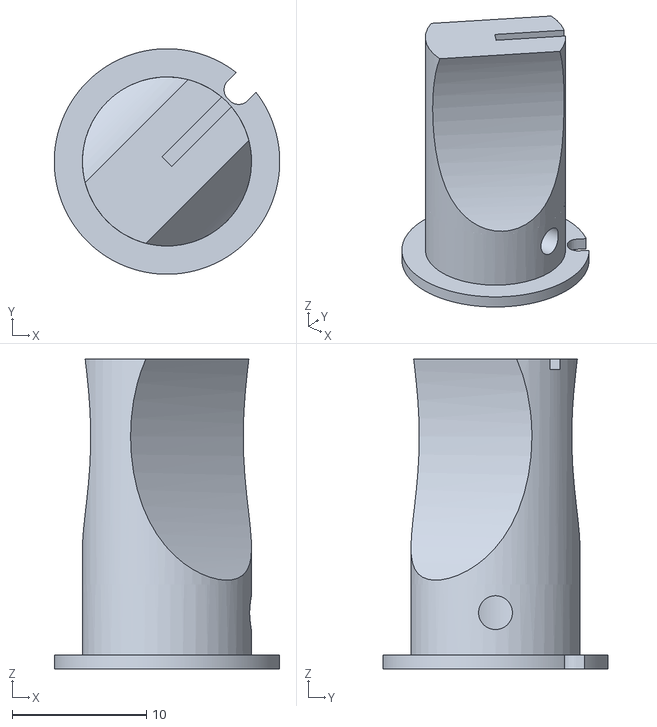
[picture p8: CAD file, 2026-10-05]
Supporting STL's/Mode_Knob_v4.stl
16.8 x 16.8 x 23.1

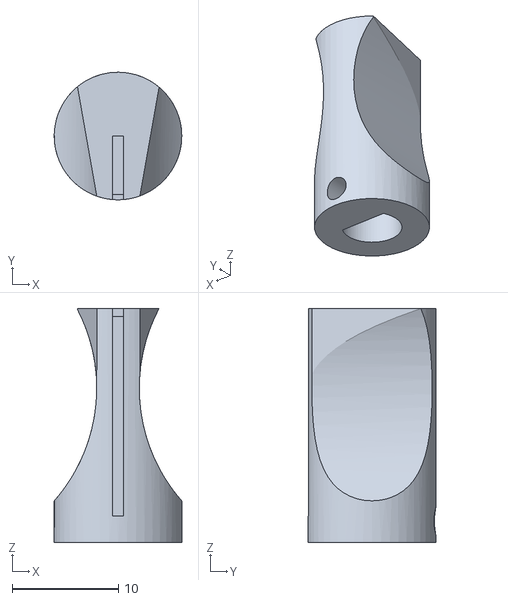
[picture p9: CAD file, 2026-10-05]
Supporting STL's/Freq_Knob_v10.stl
12.0 x 12.0 x 22.0

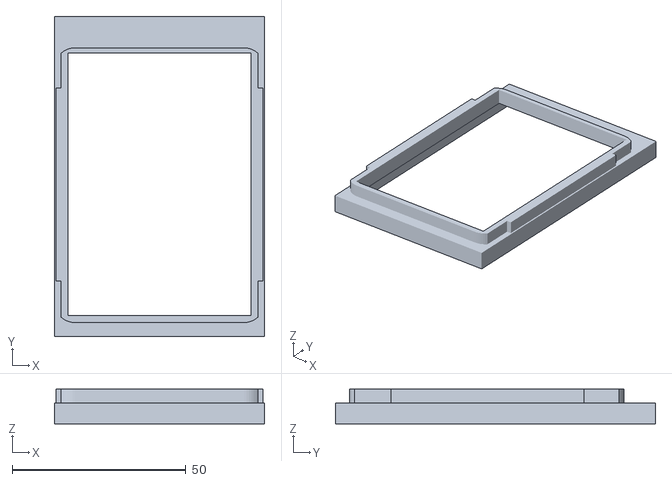
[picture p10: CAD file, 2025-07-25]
Supporting STL's/3.5-SPI-Display-Bracket-v3.stl
60.5 x 92.0 x 10.0

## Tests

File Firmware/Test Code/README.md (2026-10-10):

# Test Code

## Final hardware test HEX — October 10, 2026

**I have completed the final combined hardware test HEX file.** Download [ARC210_Final_Hardware_Test_Teensy41.hex](ARC210_Final_Hardware_Test_Teensy41.hex) and program it with Teensy Loader.

I have confirmed that all 16 buttons, six rotary encoders, TFT brightness controls and both seven-position rotary switches work together on my panel. I use physical GPIO14/A0 and GPIO15/A1 for the switch inputs, and GPIO4 for the TFT backlight. The TFT shows encoder counts and A/B readings, button states and rotary positions, ADC readings, voltage and test coverage. No DCS connection is required.

See the [combined test instructions and source](ARC210_Button_Test/). Programming this test replaces the running firmware. I have kept the earlier individual tests below for troubleshooting.

**I recommend passing the Teensy_TFT_Hello_Works test before running the encoder test.** The encoder test requires a working TFT display to show encoder counts, direction, and input states.

1. Load the [TFT hello test](Teenys_TFT_Hello_Works/Teenys_TFT_Hello_Works.ino) and confirm that its output appears correctly on the TFT. (The existing folder and sketch are named `Teenys_TFT_Hello_Works`.)
2. If the display does not work, resolve the display wiring and setup before proceeding.
3. After the TFT test passes, load [ARC210_Encoder_Check_Teensy41.hex](ARC210_Encoder_Check_Teensy41.hex) onto the Teensy 4.1 and turn each encoder in both directions. Watch its row on the TFT for changing counts and direction.

Passing the hello test confirms the display is ready; it does not install a dependency. Loading the encoder HEX replaces the hello-test firmware.

## Seven-position rotary switch TFT test

I also included a standalone [rotary switch test](ARC210_Rotary_Switch_Test/) that displays position 1–7, raw ADC reading and approximate voltage on the TFT. Connect the switch PCB's J1 pin 2 to physical Teensy **GPIO 14 (A0)**, fit all six resistors and leave JP1 open. J1 pin 1 goes to 3.3V and pin 3 to GND.

Download [ARC210_Rotary_Switch_Test.ino.hex](ARC210_Rotary_Switch_Test/ARC210_Rotary_Switch_Test.ino.hex) for Teensy Loader, or build the [sketch](ARC210_Rotary_Switch_Test/ARC210_Rotary_Switch_Test.ino). This test uses backlight **GPIO 4** and runs without DCS or an open Serial Monitor. See its [instructions](ARC210_Rotary_Switch_Test/README.md). Programming the HEX replaces the firmware on the Teensy.

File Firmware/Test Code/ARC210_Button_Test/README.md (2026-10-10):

# ARC-210 final combined hardware test

**Final hardware test HEX — October 10, 2026.** The builder confirmed all controls listed below working together on the panel.

Download [ARC210_Final_Hardware_Test_Teensy41.hex](../ARC210_Final_Hardware_Test_Teensy41.hex) and program it with Teensy Loader.

Includes the existing 16-button matrix, six rotary encoders and TFT brightness controls, plus two seven-position rotary switches on physical Teensy GPIO14 (A0) and GPIO15 (A1).

The TFT shows each switch position (SW14 and SW15), raw ADC reading, approximate voltage and number of positions tested. Serial Z resets test history and encoder counts. Hold B1 to dim or B2 to brighten, as in the original test.

Switch PCB wiring: J1 pin 1 to 3.3V, pin 2 to physical GPIO14/A0 for the first board or GPIO15/A1 for the second board, pin 3 to GND. Fit all six 1k resistors and leave JP1 open. Display backlight uses GPIO4.

Build for Teensy 4.1, USB Serial, using the ILI9488_t3 and Encoder libraries. This is a standalone hardware test and does not require DCS. Programming it replaces the firmware on the Teensy.

Compiled for Teensy 4.1 with Teensy core 1.62.0. HEX SHA-256: `8b540030c7f2831d7bc496467934c2daeb3d0237b45f5f25da5b69300f37f6a2`.

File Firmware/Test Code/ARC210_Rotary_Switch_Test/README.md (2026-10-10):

# ARC-210 seven-position rotary switch test

For the Teensy 4.1 and six-resistor rotary switch PCB. This standalone sketch shows switch position, raw ADC reading and approximate voltage on the ILI9488 TFT. USB Serial provides the same readings as an optional diagnostic. DCS and DCS-BIOS are not required.

## Wiring

| Rotary switch PCB | Teensy 4.1 |
| --- | --- |
| J1 pin 1 | 3.3V |
| J1 pin 2 | Physical pin 14 (A0) |
| J1 pin 3 | GND |

Fit all six 1k resistors R1-R6 and leave JP1 open. Use the Teensy's 3.3V rail, not 5V. The previously discussed 220-ohm series resistor and 100nF capacitor may be used at the Teensy input.

## Run

1. Open the supplied `ARC210_Rotary_Switch_Test.ino.hex` in Teensy Loader, connect the Teensy 4.1 and program it. This replaces the currently running firmware.
2. The TFT should immediately show `ARC-210 ROTARY SWITCH TEST`, even without the switch connected.
3. Rotate through all seven positions and watch the position, ADC and voltage readings on the TFT.
4. Optionally open Serial Monitor at 115200 baud for text readings.

To build from source, open `ARC210_Rotary_Switch_Test.ino` in the Arduino IDE, select Teensy 4.1 and USB Type **Serial**, then upload. It requires the `ILI9488_t3` library included in the Teensy installation used for this build.

TFT wiring: CS = 10, DC = 9, RESET = 8, MOSI = 11, SCK = 13, MISO = 12 (if connected), and backlight = **physical GPIO 4**. Backlight stays fully on. This uses the project's TFT hello-test initialization, with backlight corrected to the confirmed GPIO 4 assignment. If the screen stays blank, first check that this HEX was programmed and that the backlight and display wiring match these pins. No Serial Monitor connection is needed for the display to run.

| Position | Switch terminal | Nominal voltage | Approximate 12-bit reading |
| --- | --- | --- | --- |
| 1 | 1 | 3.300V | 4095 |
| 2 | 2 | 2.750V | 3413 |
| 3 | 4 | 2.200V | 2730 |
| 4 | 5 | 1.650V | 2048 |
| 5 | 7 | 1.100V | 1365 |
| 6 | 8 | 0.550V | 683 |
| 7 | 10 | 0.000V | 0 |

The sketch averages ADC readings and requires a position to remain stable for 75ms. Readings between tap windows are reported as BETWEEN TAPS. An unplugged input can float to a valid reading, so this is not a continuity test. If the physical knob positions appear reversed, check switch orientation against the panel markings.

Uses the Teensy core's 12-bit ADC configuration and averaging: https://www.pjrc.com/store/teensy41.html and https://github.com/PaulStoffregen/cores/blob/master/teensy4/analog.c.

Compiled for Teensy 4.1 with Teensy core 1.62.0 and its bundled ILI9488_t3 library. Hardware operation still needs checking on the actual panel.

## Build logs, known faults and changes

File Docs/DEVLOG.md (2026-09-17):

# ARC-210 Development Log

## 2026-09-17

### Teensy 4.1 TFT and DCS-BIOS Milestone

Successfully got the ARC-210 TFT display working with the Teensy 4.1.

Confirmed working display:
- 3.5-inch 480x320 SPI TFT
- ILI9488 controller
- Teensyduino-supplied `ILI9488_t3` library

Confirmed working TFT pinout:
- CS -> GPIO 10
- DC / RS -> GPIO 9
- RESET -> GPIO 8
- MOSI / SDI -> GPIO 11
- SCK -> GPIO 13
- MISO / SDO -> GPIO 12
- BLK / Backlight -> GPIO 6

Also confirmed the Teensy 4.1 is communicating with DCS through DCS-BIOS using:

```cpp
#define DCSBIOS_DEFAULT_SERIAL
#include "DcsBios.h"
```

The ARC-210 frequency was successfully received from DCS-BIOS and displayed on the TFT.

Tested live frequency received from DCS:
- 133.000 MHz

Working ARC-210 frequency buffer:

```cpp
void onArc210FrequencyChange(char* newValue) {
    // Update TFT with the new ARC-210 frequency
}

DcsBios::StringBuffer<7> arc210FrequencyBuffer(
    0x1382,
    onArc210FrequencyChange
);
```

### Status

At this point, the following has been verified:
- Teensy 4.1 is working
- TFT display is working
- TFT pinout is confirmed
- USB serial connection is working
- DCS-BIOS connection is working
- Live ARC-210 frequency data is being displayed on the TFT

### Next Steps

- Add previous frequency display
- Add preset/channel display
- Add modulation display
- Add RT number
- Add COMSEC fields
- Update only changed regions of the TFT instead of redrawing the entire screen

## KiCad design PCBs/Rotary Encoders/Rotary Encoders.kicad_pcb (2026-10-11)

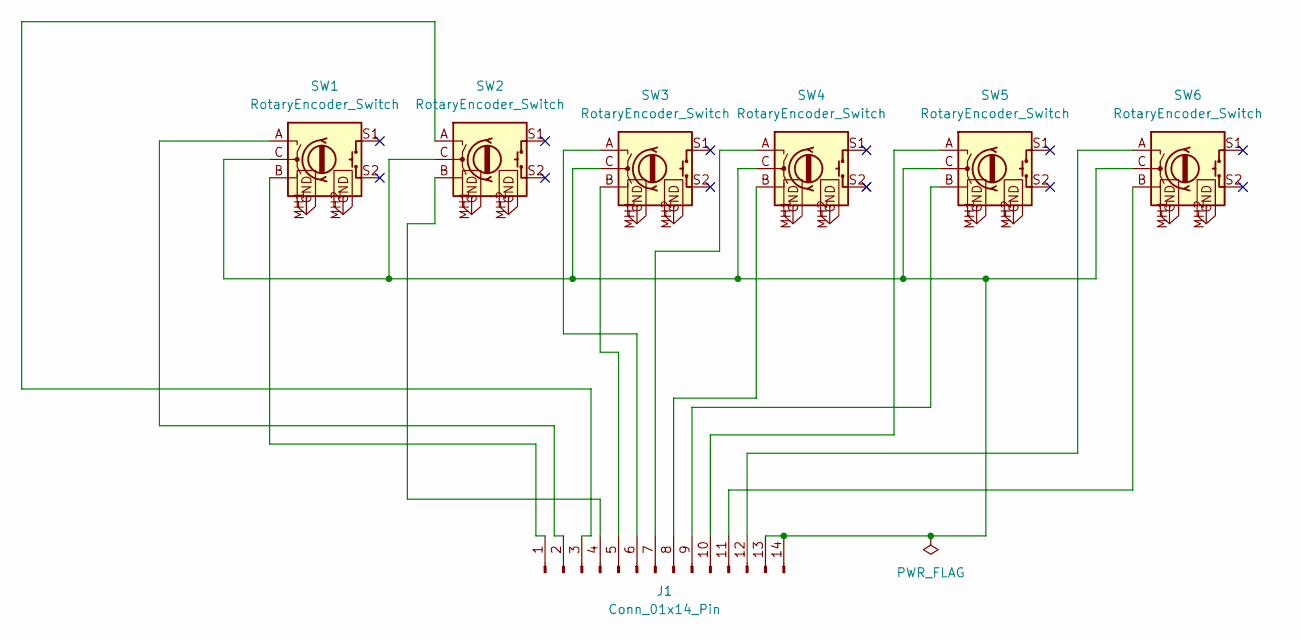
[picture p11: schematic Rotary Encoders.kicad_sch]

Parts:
J1: Conn_01x14_Pin; PinHeader_1x14_P2.54mm_Vertical
SW1, SW2, SW3, SW4, SW5, SW6: RotaryEncoder_Switch; PEC11H4220FS0024

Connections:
GND: SW1.MH1 (CASE), SW1.MH2 (CASE), SW2.MH1 (CASE), SW2.MH2 (CASE), SW3.MH1 (CASE), SW3.MH2 (CASE), SW4.MH1 (CASE), SW4.MH2 (CASE), SW5.MH1 (CASE), SW5.MH2 (CASE), SW6.MH1 (CASE), SW6.MH2 (CASE)
unnamed: J1.1, SW1.B
unnamed: J1.2, SW1.A
unnamed: J1.3, SW2.A
unnamed: J1.4, SW2.B
unnamed: J1.5, SW3.B
unnamed: J1.6, SW3.A
unnamed: J1.7, SW4.A
unnamed: J1.8, SW4.B
unnamed: J1.9, SW5.B
unnamed: J1.10, SW5.A
unnamed: J1.11, SW6.B
unnamed: J1.12, SW6.A
unnamed: J1.13, J1.14, SW1.C, SW2.C, SW3.C, SW4.C, SW5.C, SW6.C

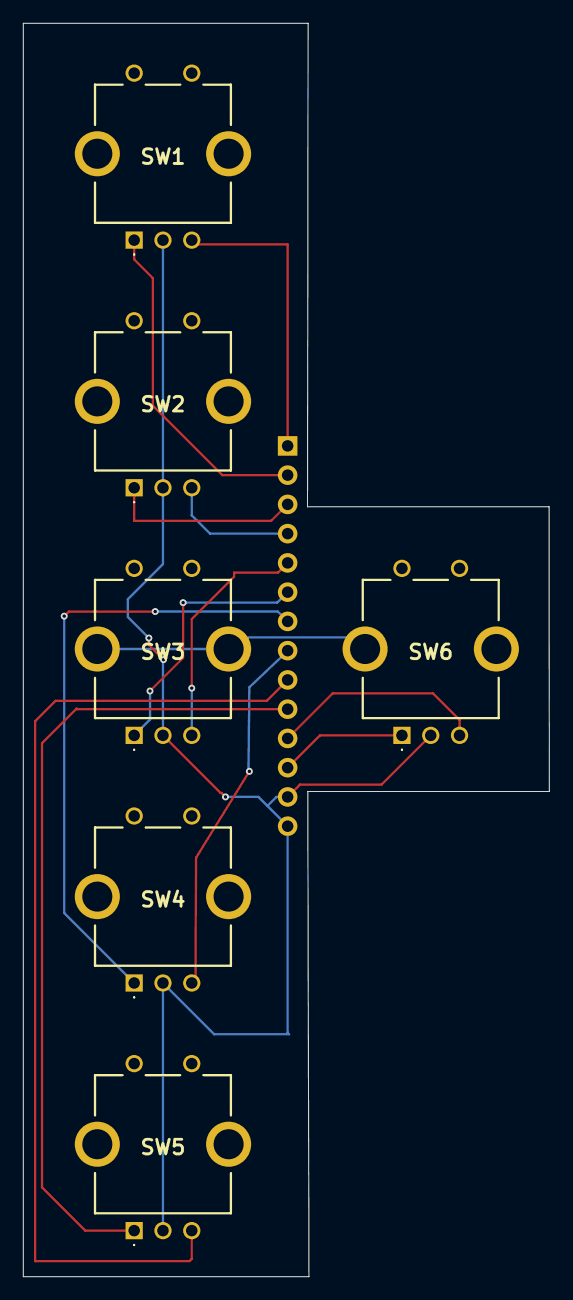
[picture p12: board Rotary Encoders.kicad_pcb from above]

Board: 2 copper layers, 45.7 x 108.8 mm, 7 parts (1 on the bottom side), 14 nets.

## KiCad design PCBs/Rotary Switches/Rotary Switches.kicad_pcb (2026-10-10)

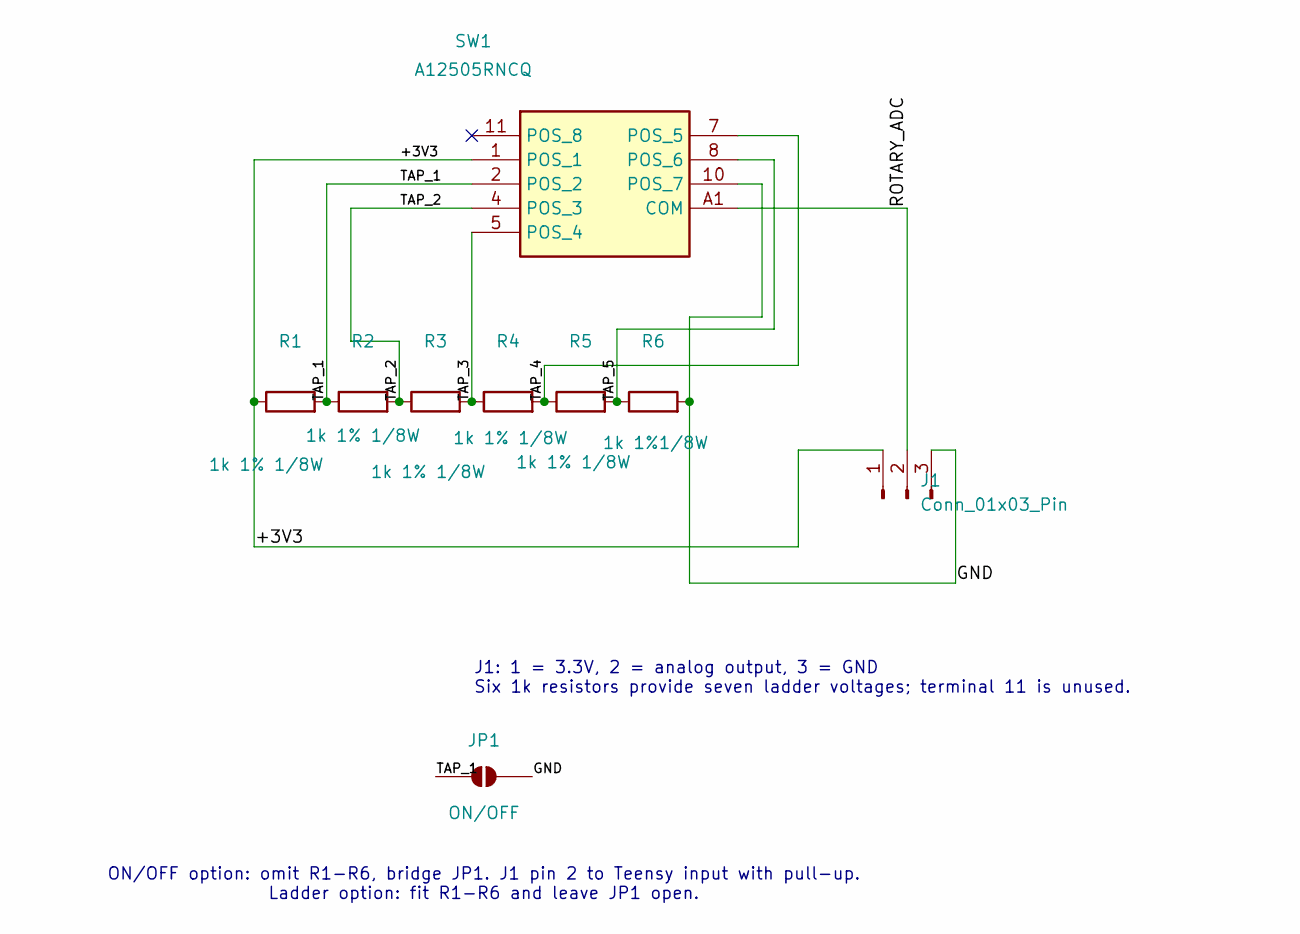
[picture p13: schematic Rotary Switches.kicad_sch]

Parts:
J1: Conn_01x03_Pin; PinHeader_1x03_P2.54mm_Vertical
JP1: ON/OFF; SolderJumper-2_P1.3mm_Open_Pad1.0x1.5mm
R1, R2, R3, R4, R5: 1k 1% 1/8W; R_Axial_DIN0204_L3.6mm_D1.6mm_P1.90mm_Vertical
R6: 1k 1%1/8W; R_Axial_DIN0204_L3.6mm_D1.6mm_P1.90mm_Vertical
SW1: A12505RNCQ

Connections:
/+3V3: J1.1, R1.1, SW1.1 (POS_1)
/GND: J1.3, JP1.2 (B), R6.2, SW1.10 (POS_7)
/ROTARY_ADC: J1.2, SW1.A1 (COM)
/TAP_1: JP1.1 (A), R1.2, R2.1, SW1.2 (POS_2)
/TAP_2: R2.2, R3.1, SW1.4 (POS_3)
/TAP_3: R3.2, R4.1, SW1.5 (POS_4)
/TAP_4: R4.2, R5.1, SW1.7 (POS_5)
/TAP_5: R5.2, R6.1, SW1.8 (POS_6)

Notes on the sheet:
ON/OFF option: omit R1-R6, bridge JP1. J1 pin 2 to Teensy input with pull-up. Ladder option: fit R1-R6 and leave JP1 open.
J1: 1 = 3.3V, 2 = analog output, 3 = GND Six 1k resistors provide seven ladder voltages; terminal 11 is unused.

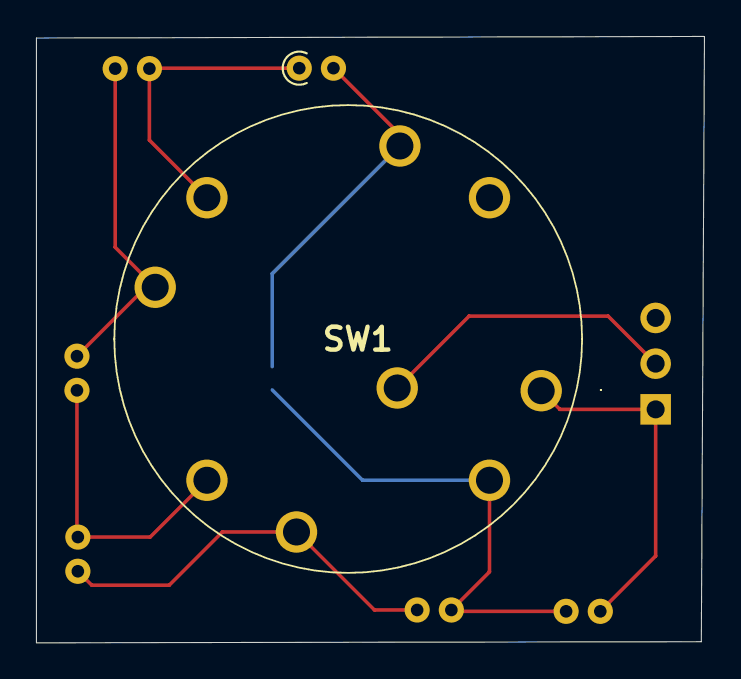
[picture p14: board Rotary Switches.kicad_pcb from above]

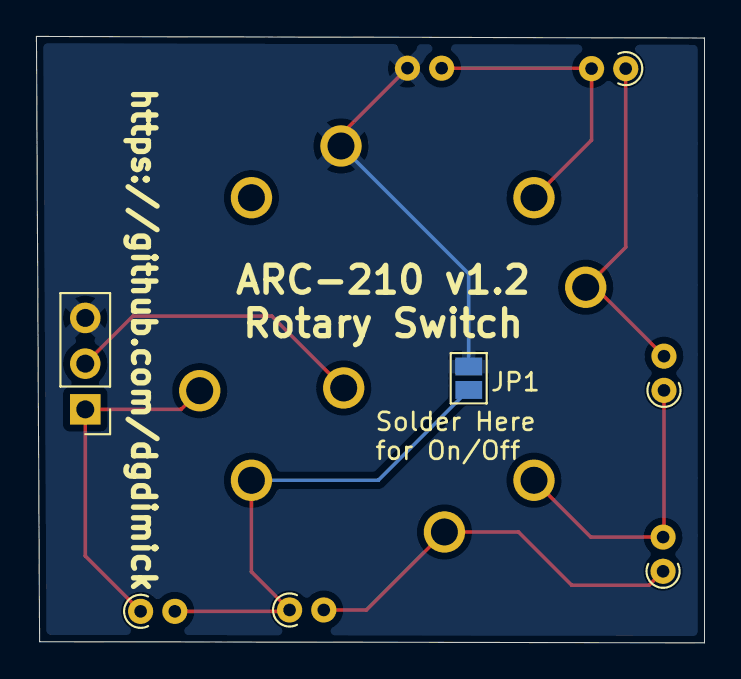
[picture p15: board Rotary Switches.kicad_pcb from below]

Board: 2 copper layers, 37.1 x 33.7 mm, 9 parts (7 on the bottom side), 8 nets.

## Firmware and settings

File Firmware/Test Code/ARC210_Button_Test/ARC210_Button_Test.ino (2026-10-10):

#include <Arduino.h>
#include <SPI.h>
#include <ILI9488_t3.h>
#include <Encoder.h>
constexpr uint8_t PAIRS[6][2]={{16,17},{28,29},{20,21},{22,23},{24,25},{26,27}};
Encoder encoders[6];
int32_t counts[6]={};
char directions[6]={'-','-','-','-','-','-'};

// Numbers printed on the Teensy 4.1 board.
constexpr uint8_t ROWS[4]={30,31,32,33};
constexpr uint8_t COLS[4]={35,36,37,40};
ILI9488_t3 tft(10,9,8);
bool rawState[16]={}, pressed[16]={}, seen[16]={};
bool held[16]={};
int activeButton=-1;
uint32_t changedAt[16]={};
uint32_t lastScan=0,lastDraw=0;
bool dirty=true,buffered=false;
int lastKey=-1;
bool lastPressed=false;
constexpr uint8_t BLK_PIN=4;
int brightness=100;
int8_t brightnessDirection=0;
uint32_t brightnessTick=0;
bool brightnessRepeating=false;


// Seven-position switch: J1 1=3.3V, 2=physical GPIO14/A0 or GPIO15/A1, 3=GND.
// Fit six 1k resistors R1-R6 and leave JP1 open.
constexpr uint8_t ROTARY_PINS[2]={14,15};
constexpr int ROTARY_EXPECTED[7]={4095,3413,2730,2048,1365,683,0};
int rotaryRaw[2]={0,0},rotaryCandidate[2]={-1,-1},rotaryPosition[2]={-1,-1};
uint8_t rotarySeen[2]={0,0};
uint32_t rotaryCandidateSince[2]={0,0},rotarySampleAt=0,rotaryDisplayAt=0;

int decodeRotary(int raw) {
  int best=0,error=4096;
  for(int i=0;i<7;++i) {
    int e=abs(raw-ROTARY_EXPECTED[i]);
    if(e<error) { error=e;best=i+1; }
  }
  return error<=200 ? best : 0;
}

void scanRotary() {
  uint32_t now=millis();
  if((uint32_t)(now-rotarySampleAt)<5) return;
  rotarySampleAt=now;
  for(uint8_t i=0;i<2;++i) {
    rotaryRaw[i]=analogRead(ROTARY_PINS[i]);
    int position=decodeRotary(rotaryRaw[i]);
    if(position!=rotaryCandidate[i]) {
      rotaryCandidate[i]=position;rotaryCandidateSince[i]=now;
    }
    if(rotaryCandidate[i]!=rotaryPosition[i] && (uint32_t)(now-rotaryCandidateSince[i])>=75) {
      rotaryPosition[i]=rotaryCandidate[i];
      if(rotaryPosition[i]>0) rotarySeen[i]|=(1u<<(rotaryPosition[i]-1));
      dirty=true;
      if(Serial) {
        Serial.print("Rotary GPIO");Serial.print(ROTARY_PINS[i]);
        Serial.print(" position: ");Serial.print(rotaryPosition[i]);
        Serial.print(" ADC: ");Serial.println(rotaryRaw[i]);
      }
    }
  }
  if((uint32_t)(now-rotaryDisplayAt)>=200) {rotaryDisplayAt=now;dirty=true;}
}

void stepBrightness(int8_t direction) {
  int next=constrain(brightness+direction*5,5,100);
  if(next==brightness) return;
  brightness=next;
  analogWrite(BLK_PIN,(brightness*255+50)/100);
  dirty=true;
}

void updateBrightness() {
  // Only the accepted button controls brightness; B1/B2 indices are 0/4.
  int8_t direction=pressed[0]==pressed[4] ? 0 : (pressed[0] ? -1 : 1);
  uint32_t now=millis();
  if(direction!=brightnessDirection) {
    brightnessDirection=direction;
    brightnessTick=now;
    brightnessRepeating=false;
    if(direction) stepBrightness(direction);
  } else if(direction && (uint32_t)(now-brightnessTick)>=(brightnessRepeating ? 100u : 400u)) {
    stepBrightness(direction);
    brightnessTick=now;
    brightnessRepeating=true;
  }
}

void scanButtons() {
  const uint32_t now=millis();
  for(uint8_t r=0;r<4;++r) {
    // Schematic: diode cathodes (striped ends) connect to rows.
    // Only the selected row drives LOW; other rows remain high impedance.
    digitalWrite(ROWS[r],LOW);
    pinMode(ROWS[r],OUTPUT);
    delayMicroseconds(10);
    for(uint8_t c=0;c<4;++c) {
      uint8_t k=r*4+c;
      bool down=digitalRead(COLS[c])==LOW;
      if(down!=rawState[k]) { rawState[k]=down; changedAt[k]=now; }
      if(down!=held[k] && (uint32_t)(now-changedAt[k])>=20) {
        held[k]=down;
        // Ignore blocked presses until they are released and pressed again.
        if(down) {
          if(activeButton>=0) continue;
          activeButton=k;
        } else {
          if(activeButton!=k) continue;
          activeButton=-1;
        }
        pressed[k]=down;
        if(down) seen[k]=true;
        lastKey=k; lastPressed=down; dirty=true;
        Serial.print("Button "); Serial.print(c*4+r+1);
        Serial.println(down ? " PRESSED" : " RELEASED");
      }
    }
    pinMode(ROWS[r],INPUT);
  }
}

void drawStatus() {
  tft.fillRect(0,32,480,288,ILI9488_BLACK);
  tft.setTextSize(2);
  for(uint8_t r=0;r<4;++r) for(uint8_t c=0;c<4;++c) {
    const uint8_t k=r*4+c;
    const int x=8+c*57,y=51+r*37;
    tft.fillRect(x,y,52,30,pressed[k] ? ILI9488_GREEN : ILI9488_BLACK);
    tft.drawRect(x,y,52,30,seen[k] ? ILI9488_GREEN : ILI9488_WHITE);
    tft.setTextColor(pressed[k] ? ILI9488_BLACK : ILI9488_WHITE);
    tft.setCursor(x+7,y+7); tft.print("B"); tft.print(c*4+r+1);
  }
  tft.setTextColor(ILI9488_WHITE);
  tft.setCursor(250,33); tft.print("ENC COUNT DIR A/B");
  for(uint8_t i=0;i<6;++i) {
    tft.setTextColor(ILI9488_GREEN);
    tft.setCursor(250,57+i*28); tft.print("R"); tft.print(i+1);
    tft.setCursor(286,57+i*28); tft.print(counts[i]);
    tft.setCursor(394,57+i*28); tft.print(directions[i]);
    tft.setCursor(420,57+i*28); tft.print(digitalRead(PAIRS[i][0]));
    tft.print("/");tft.print(digitalRead(PAIRS[i][1]));
    tft.setTextSize(1);tft.setCursor(250,74+i*28);
    tft.print("GPIO ");tft.print(PAIRS[i][0]);tft.print("/");tft.print(PAIRS[i][1]);
    tft.setTextSize(2);
  }
  tft.setTextColor(ILI9488_WHITE);
  uint8_t total=0; for(bool value:seen) if(value) ++total;
  tft.setCursor(8,216); tft.print("Tested: "); tft.print(total); tft.print("/16");
  tft.setCursor(8,243); tft.print("BLK: "); tft.print(brightness); tft.print("%");
  if(lastKey>=0) {
    tft.setCursor(8,270); tft.print("Last: B"); tft.print((lastKey%4)*4+lastKey/4+1);
    tft.print(lastPressed ? " pressed" : " released");
  }
  tft.setTextSize(1);
  tft.setCursor(8,300); tft.print("Hold B1: Dim  B2: Bright | Green: tested | Serial Z: reset");
  tft.setTextColor(ILI9488_CYAN);
  for(uint8_t i=0;i<2;++i) {
    int y=220+i*40;
    tft.setTextSize(2);
    tft.setCursor(250,y);tft.print("SW");tft.print(ROTARY_PINS[i]);tft.print(": ");
    if(rotaryPosition[i]>0) {tft.print(rotaryPosition[i]);tft.print("/7");}
    else tft.print("---");
    uint8_t tested=0;
    for(uint8_t k=0;k<7;++k) if(rotarySeen[i]&(1u<<k)) ++tested;
    tft.setTextSize(1);tft.setCursor(250,y+23);
    tft.print("ADC:");tft.print(rotaryRaw[i]);tft.print(" ");
    tft.print(rotaryRaw[i]*3.3f/4095,3);tft.print("V tested:");
    tft.print(tested);tft.print("/7");
  }
  if(buffered) tft.updateScreen();
  dirty=false;
}
void setup() {
  Serial.begin(115200);
  for(uint8_t pin:ROTARY_PINS) pinMode(pin,INPUT);
  analogReadResolution(12);
  analogReadAveraging(16);
  for(uint8_t i=0;i<6;++i) encoders[i].begin(PAIRS[i][0],PAIRS[i][1]);
  for(uint8_t pin:ROWS) pinMode(pin,INPUT);
  for(uint8_t pin:COLS) pinMode(pin,INPUT_PULLUP);
  pinMode(BLK_PIN,OUTPUT);
  analogWriteResolution(8);
  analogWriteFrequency(BLK_PIN,1000);
  analogWrite(BLK_PIN,255); // Start at full brightness.
  tft.begin(); tft.setRotation(1); tft.setTextWrap(false);
  buffered=tft.useFrameBuffer(true)!=0;
  tft.fillScreen(ILI9488_BLACK);
  tft.setTextSize(2); tft.setTextColor(ILI9488_GREEN);
  tft.setCursor(8,5); tft.print("ARC-210 CONTROLS TEST");
  tft.setTextSize(1); tft.setTextColor(ILI9488_WHITE);
  
  drawStatus();
}

void loop() {
  scanRotary();
  static uint32_t encoderReportAt=0;
  if(Serial && (uint32_t)(millis()-encoderReportAt)>=1000) {
    encoderReportAt=millis();Serial.print("Encoder inputs/counts: ");
    for(uint8_t i=0;i<6;++i) {
      Serial.print("R");Serial.print(i+1);Serial.print("=");
      Serial.print(digitalRead(PAIRS[i][0]));Serial.print("/");
      Serial.print(digitalRead(PAIRS[i][1]));Serial.print("[");
      Serial.print(encoders[i].read());Serial.print("] ");
    }
    Serial.println();
  }
  for(uint8_t i=0;i<6;++i) {
    int32_t value=encoders[i].read();
    if(value!=counts[i]) {
      directions[i]=((uint32_t)value-(uint32_t)counts[i])<0x80000000u ? '+' : '-';
      counts[i]=value; dirty=true;
    }
  }
  if(Serial.available()) {
    char c=Serial.read();
    if(c=='z' || c=='Z') {
      for(uint8_t k=0;k<16;++k) seen[k]=pressed[k];
      lastKey=-1; dirty=true;
      for(uint8_t i=0;i<2;++i) rotarySeen[i]=rotaryPosition[i]>0 ? (1u<<(rotaryPosition[i]-1)) : 0;
      for(uint8_t i=0;i<6;++i) { encoders[i].write(0); counts[i]=0; directions[i]='-'; }
    }
  }
  if((uint32_t)(millis()-lastScan)>=2) {lastScan=millis(); scanButtons(); updateBrightness();}
  if(dirty && (uint32_t)(millis()-lastDraw)>=40) {lastDraw=millis(); drawStatus();}
}

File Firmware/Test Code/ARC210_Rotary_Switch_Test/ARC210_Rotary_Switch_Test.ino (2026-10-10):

// ARC-210 seven-position resistor-ladder test for Teensy 4.1.
// J1: 1 -> 3.3V, 2 -> physical Teensy pin 14 (A0), 3 -> GND.
// Fit R1-R6 (six 1k resistors); leave JP1 OPEN.
// Select Teensy 4.1 and USB Type: Serial in the Arduino IDE.

#include <Arduino.h>
#include <ILI9488_t3.h>

constexpr uint8_t TFT_CS = 10, TFT_DC = 9, TFT_RST = 8;
constexpr uint8_t TFT_MOSI = 11, TFT_SCK = 13, TFT_MISO = 12;
constexpr uint8_t TFT_BL = 4; // Confirmed physical GPIO, not KiCad terminal 6.
ILI9488_t3 tft(TFT_CS, TFT_DC, TFT_RST, TFT_MOSI, TFT_SCK, TFT_MISO);
uint32_t lastDisplay = 0;
int displayedPosition = -99;

constexpr uint8_t SWITCH_PIN = 14;
constexpr int ADC_MAX = 4095;
constexpr float SUPPLY_VOLTS = 3.3f; // Approximate; adjust to measured 3.3V rail.
constexpr int MAX_ERROR = 200;
constexpr uint32_t SETTLE_MS = 75;
constexpr uint32_t SAMPLE_MS = 5;
constexpr uint32_t REPORT_MS = 1000;

// Position 1 is terminal 1 (+3.3V); position 7 is terminal 10 (GND).
constexpr int EXPECTED[7] = {4095, 3413, 2730, 2048, 1365, 683, 0};
constexpr uint8_t TERMINAL[7] = {1, 2, 4, 5, 7, 8, 10};

int candidate = -1;
int stablePosition = -1;
uint32_t candidateSince = 0;
uint32_t lastSample = 0;
uint32_t lastReport = 0;

// Return 1-7 for a reading close to a ladder tap, or 0 between taps.
int decodePosition(int raw) {
  int best = 0;
  int smallestError = ADC_MAX + 1;
  for (int i = 0; i < 7; ++i) {
    const int error = abs(raw - EXPECTED[i]);
    if (error < smallestError) {
      smallestError = error;
      best = i + 1;
    }
  }
  return smallestError <= MAX_ERROR ? best : 0;
}

void printReading(int raw) {
  Serial.print("Position: ");
  if (stablePosition > 0) {
    Serial.print(stablePosition);
    Serial.print(" / 7 | switch terminal: ");
    Serial.print(TERMINAL[stablePosition - 1]);
  } else {
    Serial.print("UNSET / BETWEEN TAPS");
  }
  Serial.print(" | ADC: ");
  Serial.print(raw);
  Serial.print(" | approx voltage: ");
  Serial.print(raw * SUPPLY_VOLTS / ADC_MAX, 3);
  Serial.print(" V");
  if (candidate != stablePosition) Serial.print(" | settling");
  Serial.println();
}

void updateDisplay(int raw) {
  if (displayedPosition != stablePosition) {
    tft.fillRect(15, 68, 450, 85, ILI9488_BLACK);
    tft.setTextSize(5);
    tft.setTextColor(stablePosition > 0 ? ILI9488_GREEN : ILI9488_YELLOW, ILI9488_BLACK);
    tft.setCursor(20, 82);
    if (stablePosition > 0) {
      tft.print("POS "); tft.print(stablePosition); tft.print(" / 7");
    } else {
      tft.setTextSize(3); tft.print("BETWEEN TAPS");
    }
    displayedPosition = stablePosition;
  }
  tft.fillRect(15, 160, 450, 90, ILI9488_BLACK);
  tft.setTextSize(3);
  tft.setTextColor(ILI9488_WHITE, ILI9488_BLACK);
  tft.setCursor(20, 166); tft.print("ADC: "); tft.print(raw);
  tft.setCursor(20, 202); tft.print("Volts: ");
  tft.print(raw * SUPPLY_VOLTS / ADC_MAX, 3); tft.print(" V");
  tft.fillRect(15, 254, 450, 25, ILI9488_BLACK);
  tft.setTextSize(2); tft.setCursor(20, 258);
  if (candidate != stablePosition) tft.print("Settling...");
  else if (stablePosition > 0) {
    tft.print("Switch terminal: "); tft.print(TERMINAL[stablePosition - 1]);
  } else tft.print("Check wiring / resistor values");
}

void setup() {
  pinMode(TFT_BL, OUTPUT);
  digitalWrite(TFT_BL, HIGH);
  tft.begin();
  tft.setRotation(1);
  tft.fillScreen(ILI9488_BLACK);
  tft.setTextColor(ILI9488_CYAN, ILI9488_BLACK);
  tft.setTextSize(2);
  tft.setCursor(20, 15); tft.print("ARC-210 ROTARY SWITCH TEST");
  tft.setCursor(20, 42); tft.print("Teensy 4.1 - GPIO 14 / A0");
  tft.setCursor(20, 292); tft.print("Six resistors fitted. JP1 OPEN.");
  pinMode(SWITCH_PIN, INPUT); // No pull-up on a resistor ladder.
  analogReadResolution(12);
  analogReadAveraging(16);
  Serial.begin(115200);
  Serial.println("ARC-210 seven-position rotary switch test");
  Serial.println("Input: physical GPIO 14 / A0. Six resistors fitted; JP1 OPEN.");
  Serial.println("Rotate through positions 1-7. Readings print on change and every second.");
  Serial.println("Nominal voltages: 3.300, 2.750, 2.200, 1.650, 1.100, 0.550, 0.000 V.");
  Serial.println("An unplugged/floating input cannot be reliably detected by this test.");
}

void loop() {
  const uint32_t now = millis();
  if (now - lastSample < SAMPLE_MS) return;
  lastSample = now;
  const int raw = analogRead(SWITCH_PIN);
  const int decoded = decodePosition(raw);
  if (decoded != candidate) {
    candidate = decoded;
    candidateSince = now;
  }
  bool changed = false;
  if (candidate != stablePosition && now - candidateSince >= SETTLE_MS) {
    stablePosition = candidate;
    changed = true;
  }
  if (changed || now - lastDisplay >= 150) {
    updateDisplay(raw);
    lastDisplay = now;
  }
  if (Serial && (changed || now - lastReport >= REPORT_MS)) {
    printReading(raw);
    lastReport = now;
  }
}

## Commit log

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2025-07-23 Added the PBC for the full button PCB
    [ARC-210-Master-Board-B_Cu.gbr, ARC-210-Master-Board-B_Mask.gbr, ARC-210-Master-Board-B_Paste.gbr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]
2025-07-23 Removed the stand alone Buttons directories, there wasn't any data in them
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2025-07-25 Added Bracket v3.stl
    [Bracket v3.stl]
2025-07-25 Manually renamed Bracket v.3.stl to Bracket_v.3.stl
    [Bracket v.3.stl]
2025-07-25 Remove Bracket v3.stl from GitHub
    [Bracket v.3.stl]
2025-07-25 Add 3.5-SPI-Display-Bracket v3.stl
    [3.5-SPI-Display-Bracket-v3.stl]
2025-07-25 Uploaded version 1.1 of the main board
    [ARC-210-Master-Board-B_Cu.gbr, ARC-210-Master-Board-B_Mask.gbr, ARC-210-Master-Board-B_Paste.gbr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]
2025-07-31 Added version 1.2
    [ARC-210-Master-Board-B_Cu.gbl, ARC-210-Master-Board-B_Mask.gbs, ARC-210-Master-Board-B_Paste.gbp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]
2025-07-31 Added ESP32-S3 Controler Board
    [ARC-210-ESP32S3-Board-B_Cu.gbr, ARC-210-ESP32S3-Board-B_Mask.gbr, ARC-210-ESP32S3-Board-B_Paste.gbr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]
2025-07-31 Moved ESP32-S3 Controler Board into the correct sub-dir
    [ARC-210-ESP32S3-Board-B_Cu.gbr, ARC-210-ESP32S3-Board-B_Mask.gbr, ARC-210-ESP32S3-Board-B_Paste.gbr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]
2025-07-31 Named the Button PCB correctly
    [ARC-210-Master-Board-B_Cu.gbl, ARC-210-Master-Board-B_Mask.gbs, ARC-210-Master-Board-B_Paste.gbp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]
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2025-08-07 Added STL's for the On/Off, Freq, and Mode Knobs
    [Freq Mesh v9.stl, Mode Mesh v6.stl, On_Off Knob v7.stl]
2025-08-08 Added finished Knob STL's
    [Channel Knob v13.stl]
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2025-08-15 Updated V1.2 with changes to the routing
    [ARC-210-Master-Board-B_Cu.gbl, ARC-210-Master-Board-B_Mask.gbs, ARC-210-Master-Board-B_Paste.gbp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]
2025-08-15 Remove V1.2 Gerber files
    [ARC-210-Master-Board-B_Cu.gbl, ARC-210-Master-Board-B_Mask.gbs, ARC-210-Master-Board-B_Paste.gbp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]
2025-08-15 Replaced V1.2 files
    [ARC-210-Master-Board-B_Cu.gbl, ARC-210-Master-Board-B_Mask.gbs, ARC-210-Master-Board-B_Paste.gbp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]
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2025-08-19 Removed PCB's due to design error
    [ARC-210-Master-Board-B_Cu.gbl, ARC-210-Master-Board-B_Mask.gbs, ARC-210-Master-Board-B_Paste.gbp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]
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2025-08-28 Added Button PCB Version 2.0
    [ARC-210-Master-Board_V2.0-B_Cu.gbl, ARC-210-Master-Board_V2.0-B_Mask.gbs, ARC-210-Master-Board_V2.0-B_Paste.gbp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]
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2025-09-21 Removed the On_Off Stl file, will do an Update on it
    [On_Off Knob v7.stl]
2025-09-26 added the PCB files for the Teensy control as well as updated the Button Board PCB files
    [ARC-210-ESP32S3-Board-B_Cu.gbr, ARC-210-ESP32S3-Board-B_Mask.gbr, ARC-210-ESP32S3-Board-B_Paste.gbr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]
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2026-09-02 Removed old files, turned the code base into code available on request
    [ARC-210-Master-Board_V2.0-B_Cu.gbl, ARC-210-Master-Board_V2.0-B_Mask.gbs, ARC-210-Master-Board_V2.0-B_Paste.gbp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]
2026-09-17 added a simple .ino file to test if the basic Teensy 4.1 is working
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2026-09-20 Updated the README.md file about the switchs probably going to be changed
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2026-09-25 Replace legacy FreeSans fonts with current Swansea renderer
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2026-09-26 Add master board component list to parts directory
    [BOM.csv]
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2026-10-02 Add combined button and encoder test HEX with brightness hold and button lockout
2026-10-05 Replace older knob STLs with frequency v10 and mode v4
    [Channel Knob v13.stl, Freq Mesh v9.stl, Freq_Knob_v10.stl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]
2026-10-05 Remove superseded Mode Mesh v6 STL
    [Mode Mesh v6.stl]
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2026-10-05 Add Channel Knob v3 to Knob Set V3
    [Channel_Knob_v3.stl]
2026-10-05 Replace SQL switch with matching C&K rotary switch
2026-10-05 Add A12515RNZQ SQL on/off rotary switch to BOM
    [BOM.csv]
2026-10-05 Specify 6x6x13 mm tactile buttons in BOM and parts guide
    [BOM.csv]
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2026-10-06 Drop panel illumination LEDs and resistors due to TFT clearance
    [BOM.csv]
2026-10-09 Update ARC-210 layout to five PCBs for cleaner wiring and wire support
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2026-10-10 Add rotary switch and encoder PCB pictures and update October 10 announcement
2026-10-10 Share portable Rotary Switch KiCad project and build notes
    [Rotary Switches.kicad_pcb, Rotary Switches.kicad_sch]
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2026-10-10 Withdraw Rotary Switch PCB project after finding pin-assignment error
    [Rotary Switches.kicad_pcb, Rotary Switches.kicad_sch]
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2026-10-10 Add selected PCB rotary switches and six encoders to BOM
    [BOM.csv]
2026-10-10 Restore corrected Rotary Switch PCB project as version 1.1
    [BOM.csv, Rotary Switches.kicad_pcb, Rotary Switches.kicad_sch]
2026-10-10 Release Rotary Switch PCB version 1.2 with ON/OFF solder jumper
    [Rotary Switches.kicad_pcb, Rotary Switches.kicad_sch]
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2026-10-10 Publish final hardware test HEX: buttons, encoders, brightness and two rotary switches
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2026-10-11 Publish checked Rotary Encoder PCB project and wiring instructions
    [Rotary Encoders.kicad_pcb, Rotary Encoders.kicad_sch]
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2026-10-11 Remove outdated Button PCB V2.0 image to prevent confusion; this is not the final PCB
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2026-10-11 Update radio layout to six PCBs and clarify On/Off rotary switch assembly
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2026-10-11 Publish Rotary Encoder PCB v1.1 with corrected power GND connections
2026-10-11 Announce Rotary Encoder PCB v1.1 and corrected power GND connections
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2026-10-11 Correct parts README to six PCBs and explain shared rotary switch board design
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2026-10-12 Replace display bracket with Deep Bracket v5
2026-10-12 Use correct A12505RNCQ through-hole switch 3D model
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2026-10-22 Use consistent v. revision format for all STLs and version encoder spacer v.1
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2026-10-22 Replace shaft spacer with test-fitted v.5 clearance fix
2026-10-22 Set PCB budget to $75, revise build total, and fix encoder supplier URL
2026-10-22 Specify 6x6x5mm button switches and correct Amazon supplier link
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2026-10-22 Clarify future lighting needs new button PCB after ARC-164 and ARC-184 projects
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2026-10-25 Add October 24 update on optional SQL board and planned Master solder pads
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2026-10-25 Publish Master Board schematic with portable KiCad libraries and public download links
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2026-10-27 Remove isolated copper fills from Button Matrix PCB and update clean DRC results
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2026-10-27 Add manufacturing Gerbers and drills for Rotary Encoder v1.4 and Rotary Switch v2.0
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2026-10-27 Release final Button Matrix PCB v3.1 with regenerated Gerbers, drills and fit-confirmed documentation
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2026-10-27 Confirm physical test fit of final Button Matrix v3.1 in all three READMEs
2026-10-27 Publish USB-powered Main Board draft with direct 3.3V TFT supply and updated build documentation
2026-10-27 Remove Main Board C5/C6 to match tested direct TFT wiring; retain C1/C2 and update BOM/docs
2026-10-27 Include Teensy 4.1 STEP model and project-relative U1 attachment with 3D Viewer instructions
2026-10-27 Add Main PCB 3D preview with Teensy and embed in Main Board README
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2026-10-28 Add Main PCB layout progress and Teensy 3D picture to PCB overview
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2026-10-29 docs: explain five required PCBs and optional SQL board in Main Board README
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2026-10-29 Upload corrected Main Board PCB and refresh validation status
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2026-10-29 Explain clearance-based stand-off selection and 22–26 mm height guide
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2026-10-30 Document low-priority rotary-switch wiring redesign idea
2026-10-30 Clarify redesign cost tradeoff and possible LED backlighting
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2026-10-30 Shorten Teensy speed comparison in Features
2026-10-30 Document SQL clearance-hole manufacturing correction in project updates
2026-10-30 Release Button Matrix v3.2 with fresh manufacturing exports and latest update preview
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2026-10-30 Preserve future button lighting redesign details and priorities
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2026-10-31 Note possible display bracket redesign after PCB assembly
2026-10-31 Keep display bracket redesign plan in Future Thoughts
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2026-10-31 Clarify LED backlighting requires a redesigned button board
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2026-10-31 Align documentation on required button board redesign for LEDs
2026-10-31 Add main README note on button backlighting redesign
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2026-10-31 Make LED redesign notes consistent and explicitly undated
2026-10-31 Note possible four-layer PCB costs for future lighting redesign
2026-10-31 Explain removable Teensy mounting and replacement-board savings
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2026-10-31 Flag SQL switch travel mismatch and pending replacement
2026-10-31 Flag pending SQL switch replacement in README and Build Guide
2026-10-31 Add SQL switch replacement note to PCB guides
2026-10-31 Add SQL switch replacement note to button board README
2026-10-31 Align SQL switch replacement notes and remove misleading travel guidance
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2026-10-31 Track SQL switch replacement in Future Thoughts
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2026-11-01 Document verified bridge V1.5.4 power-cycle fix
2026-11-01 Highlight verified V1.5.4 bridge power-cycle fix
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2026-11-01 Track missing on-screen versions in legacy hardware tests
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2026-11-01 Correct pronoun in 3D-printing help sentence
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2026-11-03 Plan future frequency rotary-switch hardware redesign
2026-11-03 Correct proposed PCB offer to Version 2 builders
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2026-11-03 Restore ARC-210 to its November 2 morning state
    Restore tracked files to commit 193abb4, which was current at 3:26 AM MST on November 2, 2026. Revert the five later commits without rewriting history.
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2026-11-03 Plan correct frequency rotary switches for ARC-210 Version 2
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2026-11-12 Document TFT orientation for SQL spacer clearance
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2026-11-13 Document soldering shorter parts first
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
